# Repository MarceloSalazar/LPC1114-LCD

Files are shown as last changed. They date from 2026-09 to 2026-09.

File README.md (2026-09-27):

# LPC1114-LCD

Placa basada en el microcontrolador **NXP LPC1114FN28 (ARM Cortex-M0, DIP-28)** con pantalla **LCD 1602**, LEDs,
pulsadores y buzzer. Su uso principal es un **temporizador Pomodoro**, aunque también sirve como reloj con alarma.
Se programa en C.

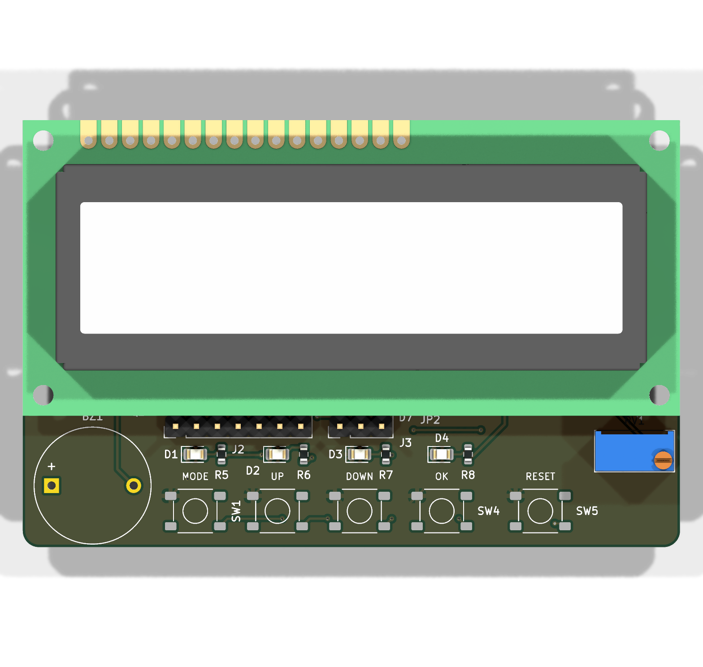
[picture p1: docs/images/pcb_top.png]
PCB, vista superior


**Esquemático:** [docs/hardware/LPC1114-LCD_schematic.pdf](docs/hardware/LPC1114-LCD_schematic.pdf)

| Fase | Contenido | Estado |
|---|---|---|
| 1 | Hardware v1.2: PCB de 2 capas montado por JLCPCB (PCBA) con componentes Basic | Listo para fabricar |
| 1b | Caja impresa en 3D de dos piezas (FreeCAD) | Lista: STEP + STL en [enclosure/](enclosure) |
| 2 | Firmware en C: temporizador Pomodoro / reloj (+ tests) | Pendiente |

## Características (v1.2)

- **MCU**: LPC1114FN28/102, 50 MHz, 32 kB flash, 4 kB RAM, en zócalo DIP-28. La base de tiempos es un cristal de 12 MHz de ±10 ppm.
- **Alimentación**: micro USB (5 V) con protección ESD USBLC6-2SC6 y regulador XC6206 de 3,3 V.
  Si no montas el USBLC6, puenteas con estaño **JP3** y **JP4**.
- **USB-serie**: CH340C en el mismo conector micro USB. Además, pads UART de 1 × 3 (GND, RX, TX) a 3,3 V.
  Con los puentes **JP5** y **JP6** eliges si la UART del MCU va al CH340 (de fábrica) o a J3.
- **Programación**: pads de 1 × 7 (3V3, SWDIO, SWCLK, RESET, GND, SCL, SDA) para un programador CMSIS-DAP.
  Los pines SCL y SDA quedan libres para módulos I2C. También se puede programar con el bootloader ISP por UART,
  de forma automática si se cierran los puentes JP1 y JP2.
- **LCD 1602** en modo 4 bits, montado encima del PCB. El footprint es de 18 pines: 16 estándar más 2 para módulos RGB.
  La retroiluminación se regula por PWM y el contraste con un trimmer multivuelta.
- **Interfaz de usuario**: 4 pulsadores (MODE/ISP, UP, DOWN, OK), RESET, 3 LEDs y LED de encendido,
  y buzzer piezoeléctrico TDK PS1420P02CT.
- **RTC opcional (DNP)**: la cara inferior tiene la huella de un DS3231MZ, su condensador y un portapilas CR2032 SMD, en el bus I2C de J2.
  No se montan; quedan para una ampliación futura.
- **PCB**: **80 × 52 mm**, 2 capas. JLCPCB monta todos los componentes SMD (una sola cara, casi todos Basic).
  Tú sueldas 7 componentes: el LPC1114, el LCD, el trimmer, el buzzer, el USBLC6 y las 2 tiras de pines.

## Estructura del repositorio

```
LPC1114-LCD/
├── hardware/                 Proyecto KiCad 10
│   ├── LPC1114-LCD.kicad_pro/.kicad_sch/.kicad_pcb
│   ├── lib/                  Símbolos y footprints propios
│   ├── fabrication/          Gerber (.zip), BOM + CPL de JLCPCB, soldadura manual, opciones DNP, STEP
│   └── scripts/              export_fab.ps1: ERC/DRC y generación de todos los ficheros
├── enclosure/                Caja 3D (FreeCAD): script paramétrico, STEP y STL
├── firmware/                 Fase 2 (en C)
│   ├── app/                  Aplicación; inc/board.h contiene el mapa de pines
│   ├── lib/                  CMSIS / drivers
│   └── tests/                Tests unitarios
└── docs/
    ├── datasheets/           Hojas de datos
    ├── hardware/             Notas de diseño, revisión para JLCPCB, esquemático en PDF
    └── images/               Renders del PCB y de la caja
```

## Mapa de pines (LPC1114FN28)

| Pin | Puerto | Función en la placa | Notas |
|----:|---|---|---|
| 1  | PIO0_8  | BTN_OK (SW4) | Activo en bajo, pull-up de 10k |
| 2  | PIO0_9  | BTN_UP (SW2) | Activo en bajo |
| 3  | SWCLK | SWD (J2-3) | |
| 4  | PIO0_11 | LCD_BL (PWM CT32B0_MAT3) | Retroiluminación, activo en alto. IOCON FUNC=1 |
| 5  | PIO0_5  | I2C SDA (J2-7) | Expansión y RTC opcional; pull-up de 4k7 |
| 6  | PIO0_6  | LCD D7 | |
| 9  | PIO1_0  | LCD D6 | IOCON FUNC=1 |
| 10 | PIO1_1  | LCD D5 | IOCON FUNC=1 |
| 11 | PIO1_2  | LCD D4 | IOCON FUNC=1 |
| 12 | SWDIO | SWD (J2-2) | |
| 13 | PIO1_4  | LCD E | |
| 14 | PIO1_5  | LCD RS | |
| 15 | PIO1_6  | UART RXD | Desde el CH340 (1k en serie) o J3-2, según JP5 |
| 16 | PIO1_7  | UART TXD | Hacia el CH340 o J3-3, según JP6 |
| 17 | PIO1_8  | BTN_DOWN (SW3) | Activo en bajo |
| 18 | PIO1_9  | BUZZER (PWM CT16B1_MAT0) | Activo en alto (NPN hacia el piezo a 5 V) |
| 19/20 | XTALOUT/XTALIN | Cristal de 12 MHz | |
| 23 | RESET | RESET (SW5, J2-4, CH340 DTR vía JP1) | |
| 24 | PIO0_1  | BTN_MODE (SW1) / ISP | Pulsado durante el reset: arranca el bootloader UART |
| 25 | PIO0_2  | LED1 (rojo) | Activo en alto |
| 26 | PIO0_3  | LED2 (amarillo) | Activo en alto |
| 27 | PIO0_4  | I2C SCL (J2-6) | Expansión y RTC opcional; pull-up de 4k7 |
| 28 | PIO0_7  | LED3 (verde) | Activo en alto |

El LCD tiene R/W a GND (solo escritura) y se controla con lógica de 3,3 V. Este mapa también está en
[firmware/app/inc/board.h](firmware/app/inc/board.h).

## Fabricación y montaje en JLCPCB

1. En <https://jlcpcb.com>, sube [hardware/fabrication/LPC1114-LCD_JLCPCB.zip](hardware/fabrication/LPC1114-LCD_JLCPCB.zip)
   y elige 2 capas, 1,6 mm, HASL y el color que quieras.
   En *Remove Order Number* selecciona **Specify a location**: JLCPCB pone el número en la cara inferior, donde está el texto `JLCJLCJLCJLC`.
2. Activa **PCB Assembly**, en cara superior (*Top side*), y sube:
   - BOM: [LPC1114-LCD_JLCPCB_BOM.csv](hardware/fabrication/LPC1114-LCD_JLCPCB_BOM.csv) (24 líneas, cada una con su código LCSC).
   - CPL: [LPC1114-LCD_JLCPCB_CPL.csv](hardware/fabrication/LPC1114-LCD_JLCPCB_CPL.csv).
3. Antes de confirmar, **revisa la orientación de cada pieza** en la vista previa de JLCPCB. Presta especial atención a los SOT-23, SOIC-16, cristal,
   micro USB y pulsadores; si alguno aparece girado, corrígelo ahí mismo.
4. La lista de componentes que sueldas tú está en [LPC1114-LCD_hand_solder.csv](hardware/fabrication/LPC1114-LCD_hand_solder.csv).
   Los componentes opcionales (DNP) del RTC están en [LPC1114-LCD_DNP_options.csv](hardware/fabrication/LPC1114-LCD_DNP_options.csv).

### Puentes de soldadura

| Puente | De fábrica | Qué hacer |
|---|---|---|
| JP1 / JP2 | Abiertos | Ciérralos para que el CH340 controle RESET e ISP (`lpc21isp -control`) |
| JP3 / JP4 | Abiertos | Ciérralos **solo si no montas el USBLC6 (U5)** |
| JP5 / JP6 | 1-2 puenteado (CH340) | Para usar una UART externa en J3: corta la pista 1-2 y puentea 2-3 en los dos |

Detalles, tipo de cada componente y decisiones:
[docs/hardware/design-notes.md](docs/hardware/design-notes.md) y
[docs/hardware/schematic-review-jlcpcb.md](docs/hardware/schematic-review-jlcpcb.md).

Para regenerar los ficheros después de modificar el diseño en KiCad:

```powershell
powershell -ExecutionPolicy Bypass -File hardware\scripts\export_fab.ps1
```

## Caja

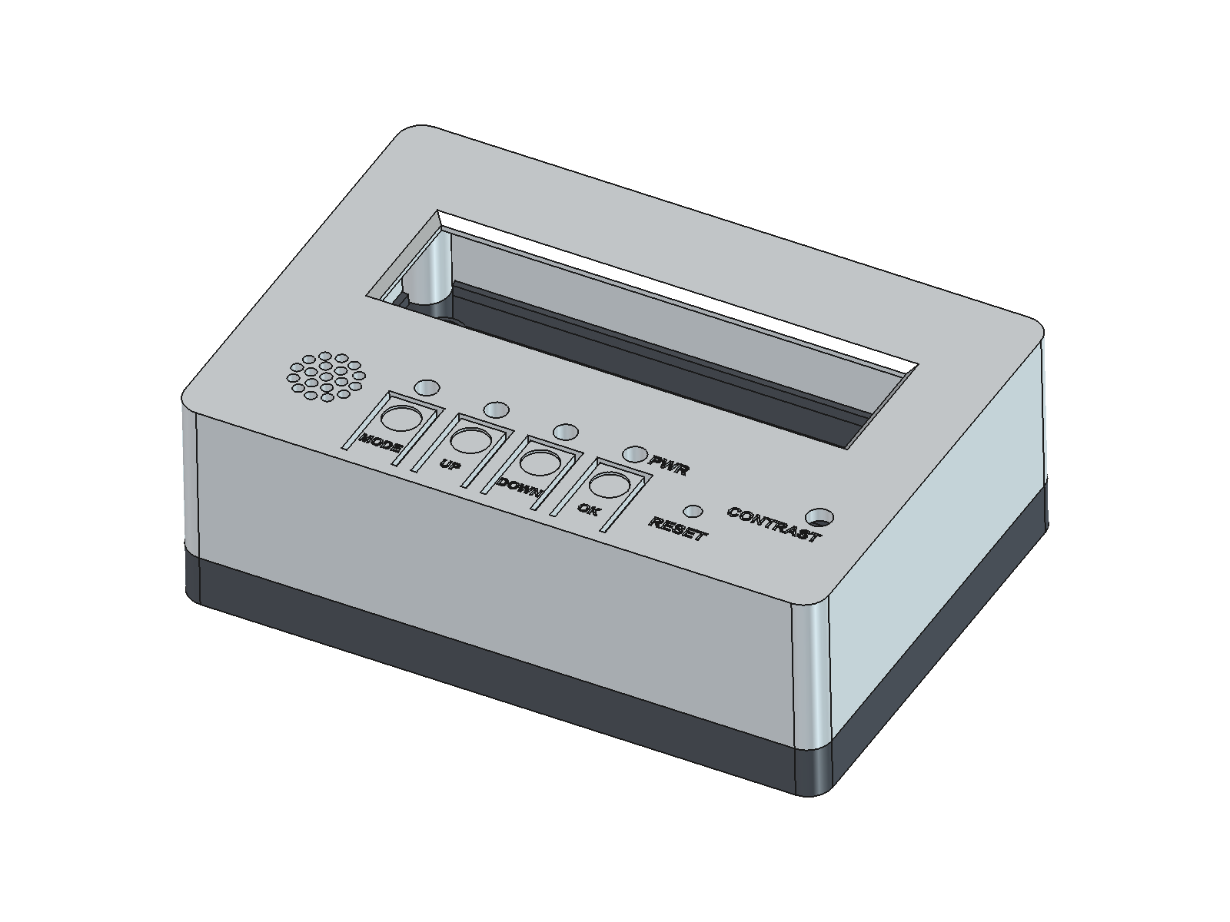
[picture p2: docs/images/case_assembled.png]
Caja montada


Dos piezas, la superior con el display y la inferior como base, de **92,8 × 64,8 × 31,4 mm**, unidas con 4 tornillos M3 × 16 desde abajo.
Los pulsadores van integrados en la tapa y los LEDs se ven a través de guías de luz de metacrilato de Ø3 mm.
Detalles, impresión y tornillería en [enclosure/README.md](enclosure/README.md).

## Programación (fase 2)

- **SWD**: conecta un programador CMSIS-DAP a J2 y usa [pyOCD](https://pyocd.io) (`pyocd flash -t lpc1114fn28 app.hex`) u OpenOCD.
- **UART ISP**: mantén MODE pulsado, pulsa RESET y usa `lpc21isp` o Flash Magic en el puerto COM del CH340.
  Con JP1 y JP2 cerrados con estaño, `lpc21isp -control` lo hace solo.

## Licencia

[MIT](LICENSE): hardware, firmware y documentación de este repositorio. Las hojas de datos de `docs/datasheets/` pertenecen a sus fabricantes.

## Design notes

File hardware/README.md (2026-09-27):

# Hardware: proyecto KiCad 10

| Fichero | Contenido |
|---|---|
| `LPC1114-LCD.kicad_pro` | Proyecto: clases de red (Default 0,25 mm; Power 0,3 mm para GND, +3V3, retroiluminación y buzzer) y reglas |
| `LPC1114-LCD.kicad_sch` | Esquemático (una hoja A3, organizada en bloques) |
| `LPC1114-LCD.kicad_pcb` | PCB de 2 capas, 80 × 52 mm (v1.2); RTC opcional y puentes en la cara inferior |
| `lib/LPC1114-LCD.kicad_sym` | Símbolos propios: `LPC1114FN28` (DIP-28), `LCD1602` (18 pines), `CH340C` (V3 como entrada de alimentación) |
| `lib/LPC1114-LCD.pretty/` | Footprints propios: `LCD1602_18pin` (fila de 1 × 18, taladros M2.5 de 75 × 31 mm), `SW_TS-1187A_5.1x5.1mm` (pulsador SMD) y `Buzzer_TDK_PS1420P02CT_D14mm_P10mm` |
| `fabrication/` | Gerber para JLCPCB (`.zip`), **BOM y CPL de PCBA** (`*_JLCPCB_BOM.csv`, `*_JLCPCB_CPL.csv`), lista de soldadura manual (`*_hand_solder.csv`), BOM completa y modelo 3D (`.step`) |
| `scripts/export_fab.ps1` | ERC y DRC, y exportación de todos los ficheros de fabricación y documentación |

Las librerías del proyecto se referencian con `${KIPRJMOD}` en `sym-lib-table` y `fp-lib-table`, así que el proyecto
se abre directamente sin configurar nada. El resto de símbolos, footprints y modelos 3D son los estándar de KiCad 10.

## Flujo de trabajo

1. Edita el esquemático y el PCB en KiCad.
2. En el PCB: *Herramientas → Actualizar PCB desde el esquemático* (F8) y vuelve a rellenar las zonas (B).
3. Ejecuta el script desde la raíz del repositorio:

   ```powershell
   powershell -ExecutionPolicy Bypass -File hardware\scripts\export_fab.ps1
   ```

   El script se detiene si el ERC o el DRC encuentran errores. Si todo es correcto, regenera
   `fabrication/LPC1114-LCD_JLCPCB.zip`, la BOM y la CPL de JLCPCB, la lista de soldadura manual, el STEP, el PDF del
   esquemático y los renders de `docs/images`.

## Campos de los símbolos

- `LCSC`: código de la pieza en JLCPCB/LCSC. Los símbolos que lo tienen los monta JLCPCB y entran en la BOM y la CPL de PCBA.
- `Assembly = USER`: componentes que se sueldan a mano (U1, DS1, RV1, BZ1, U5, J2, J3).
- **DNP** (atributo *Do Not Populate* y `Assembly = DNP ...`): RTC opcional U4, C9 y BT1 en la cara inferior.
  No entran en la BOM ni la CPL de JLCPCB; el script los lista en `fabrication/LPC1114-LCD_DNP_options.csv`.

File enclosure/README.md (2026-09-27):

# Caja impresa en 3D

Caja de dos piezas para la placa LPC1114-LCD v1.2: la **superior** (display) y la **inferior** (base).
Se cierra con **4 tornillos M3 × 16** que entran desde abajo.

| Montada | Despiece |
|---|---|
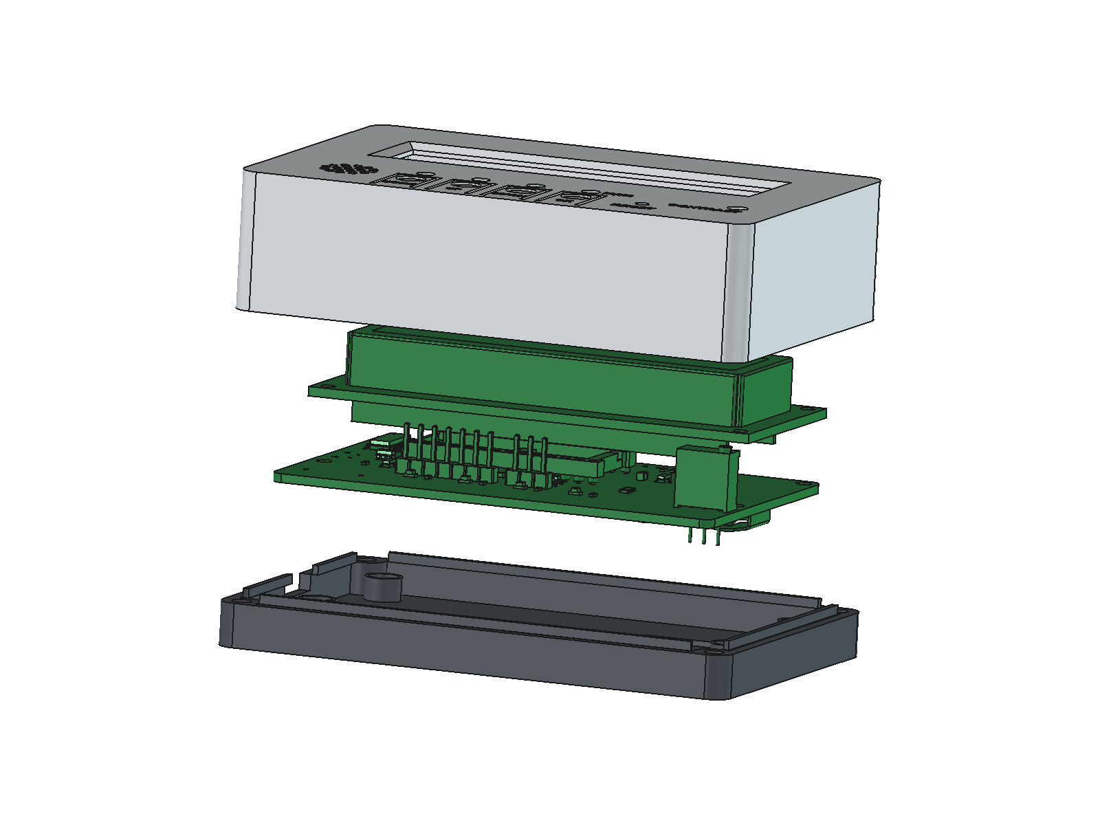
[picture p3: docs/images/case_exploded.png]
Despiece
| Caja montada |  |
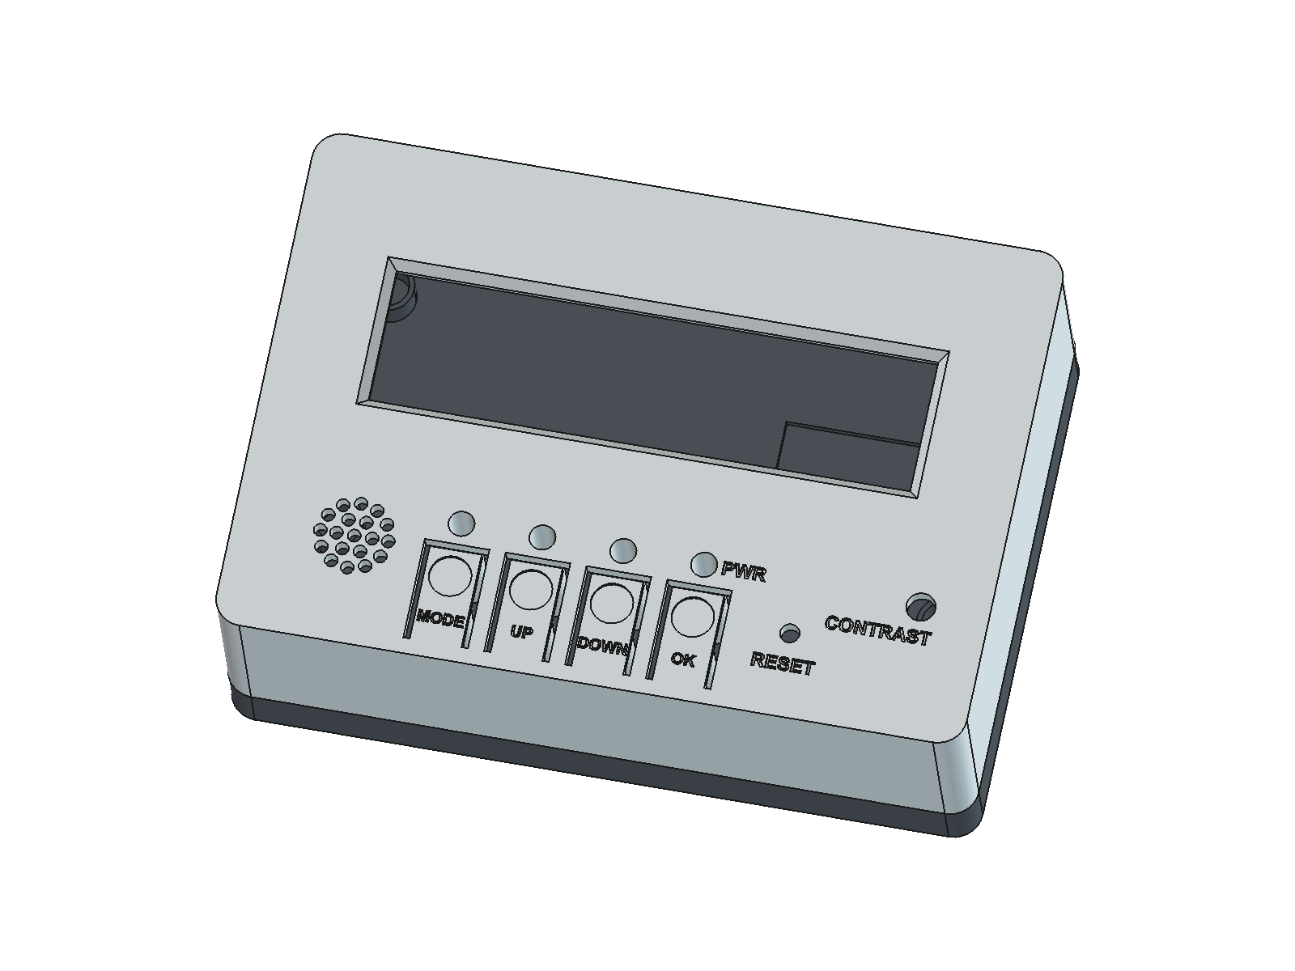
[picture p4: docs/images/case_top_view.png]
Vista superior
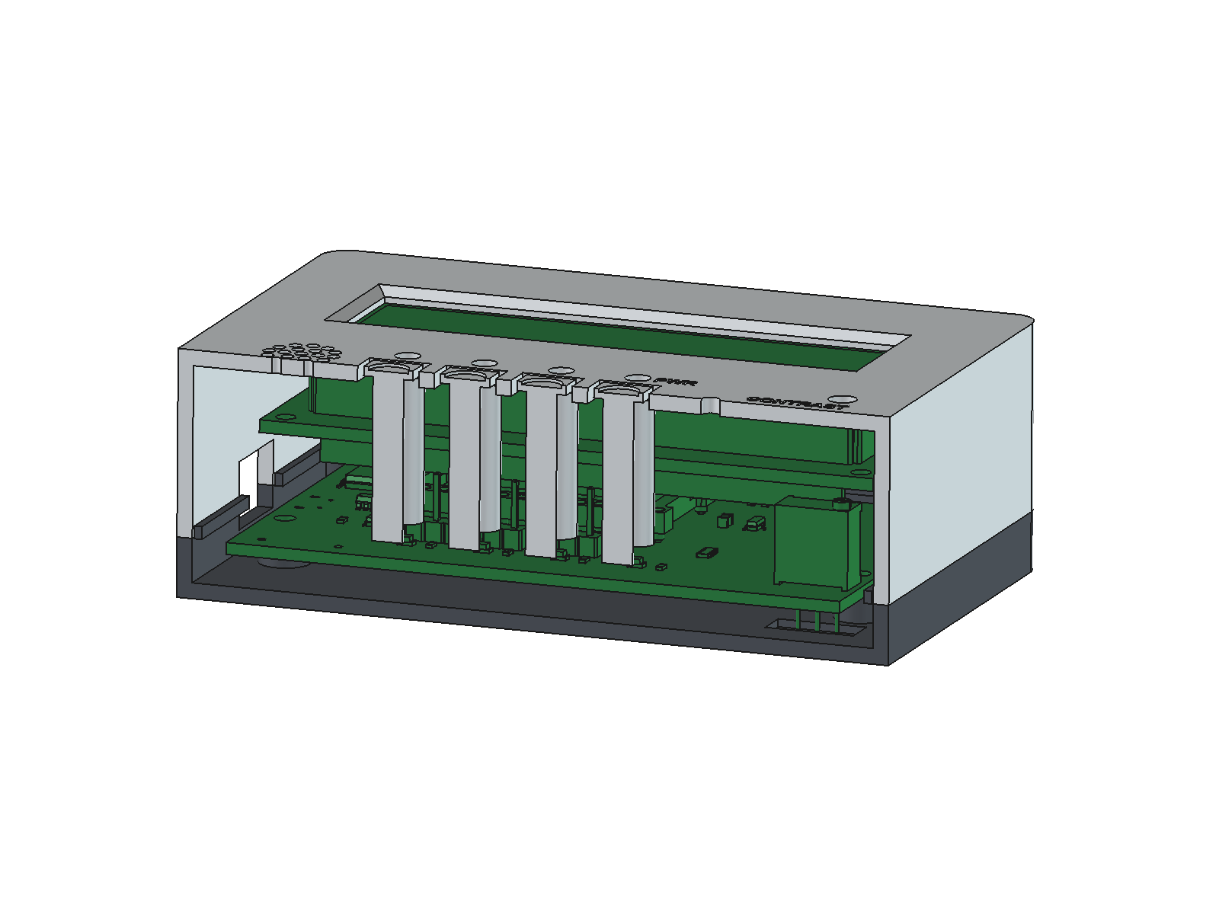
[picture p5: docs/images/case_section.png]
Corte por los pulsadores
|  |  |

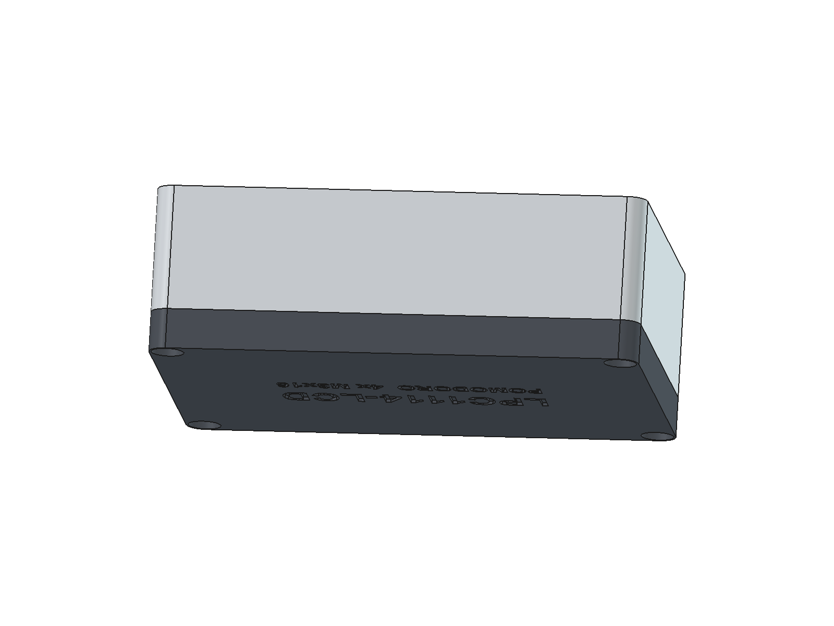
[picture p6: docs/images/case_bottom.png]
Vista inferior


## Ficheros

| Fichero | Uso |
|---|-----|
| `case_top.step`, `case_base.step` | Modelo CAD de cada pieza |
| `case_assembly.step` | Las dos piezas y el PCB con sus componentes (para comprobar ajustes) |
| `case_top.stl`, `case_base.stl` | Para el laminador, ya en la orientación de impresión |
| `LPC1114-LCD_case.FCStd` | Documento de FreeCAD |
| `case.py` | Script paramétrico que genera todo lo anterior |
| `render.py` | Genera las imágenes de `docs/images/case_*.png` |

## Características (v1.2)

- Medidas exteriores: **92,8 × 64,8 × 31,4 mm**. Paredes y fondo de 2 mm; la unión entre piezas está a la altura de la cara superior del PCB.
- **Ventana del LCD** de 67 × 17 mm con chaflán exterior. La tapa apoya sobre el marco del LCD (holgura de 0,2 mm).
- **Pulsadores integrados**: cada lengüeta flexible de la tapa (1,2 mm de grosor) tiene un vástago que baja hasta el
  pulsador SMD TS-1187A (1,5 mm de alto), con 0,4 mm de holgura.
- **Guías de luz** para los 4 LEDs SMD: agujeros de Ø3,2 mm con un tubo que baja hasta 2,2 mm por encima del LED.
  Van con varilla de metacrilato de Ø3 mm y unos 22 mm de largo (desde la superficie de la tapa hasta casi tocar el LED).
- Agujeros para el RESET (se pulsa con un clip) y el ajuste de **contraste** (tornillo del trimmer), rejilla para el buzzer y
  abertura para el **micro USB** en el lateral izquierdo.
- La base tiene 4 tubos bajo los taladros del LCD. En ellos se alojan las cabezas de los tornillos M2.5 que unen el PCB a los separadores del LCD.
  Al cerrar la caja, el PCB queda sujeto entre los tubos de la base y la tapa, que apoya sobre el LCD. Un labio perimetral centra la tapa.
- Comprobado en FreeCAD: **0 mm³ de interferencia** entre las dos piezas y el PCB (con el LCD a su altura real y las tiras J2/J3).
  Los pulsadores SMD, el buzzer y el micro USB no tienen modelo 3D en KiCad, así que los he comprobado con sus medidas.
- La base tiene un rebaje de 1 mm bajo el portapilas CR2032 del RTC opcional (cara inferior del PCB), así que se puede montar sin cambiar la caja.
- J2 (SWD) y J3 (UART) quedan dentro. Para programar por SWD hay que abrir la caja; con ella cerrada se puede programar por el USB (bootloader ISP).

## Impresión (PLA o PETG)

| Pieza | Orientación | Notas |
|---|---|---|
| Superior | Cara del display apoyada en la cama (el STL ya está girado) | Capa de 0,2 mm, 3 perímetros, relleno del 20 %. No necesita soportes. |
| Base | Fondo apoyado en la cama | Sin soportes. |

## Tornillería y piezas

| Cantidad | Pieza | Uso |
|---:|---|-----|
| 4 | Tornillo M3 × 16 (cabeza cilíndrica o alomada, Ø ≤ 6 mm) | Cierre de la caja desde abajo; rosca en el plástico (taladro guía de Ø2,5 mm) |
| 4 | Separador M2.5 de 11 mm hembra-hembra | LCD sobre el PCB |
| 8 | Tornillo M2.5 × 5 (cabeza de Ø ≤ 4,5 mm) | 4 arriba (LCD) y 4 abajo (PCB); las cabezas de abajo quedan dentro de los tubos de la base |
| 4 | Varilla de metacrilato de Ø3 mm y ~22 mm | Guías de luz de los LEDs |

Si prefieres insertos roscados de latón (M3, Ø4 × 5,7 mm), cambia `PILOT_D = 4.0` en `case.py` y regenera los ficheros.

## Montaje

1. Monta el LCD sobre el PCB con los separadores de 11 mm y corta las patillas de la cara inferior a menos de 2,5 mm.
2. Coloca el conjunto en la base: las cabezas de los tornillos M2.5 entran en los 4 tubos.
3. Mete las 4 varillas de luz en la tapa y ciérrala. El labio de la base la centra. Comprueba que los 4 pulsadores hacen clic.
4. Cierra con los 4 tornillos M3 × 16 desde abajo.

## Modificar la caja

Todas las medidas son parámetros al principio de `case.py`: holguras, grosores, altura del LCD (`LCD_STACK`), ventana, etc.
Para regenerar los ficheros STEP, STL y FCStd:

```powershell
& "C:\Program Files\FreeCAD 1.1\bin\freecadcmd.exe" enclosure\case.py
```

Las imágenes se regeneran con `render.py` desde la interfaz de FreeCAD (menú *Macro*) o lanzando `freecad.exe` con el script.

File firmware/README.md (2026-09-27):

# Firmware (fase 2): temporizador Pomodoro / reloj

> Pendiente. Esta carpeta contiene de momento la estructura y el mapa de pines de la placa.

## Estructura prevista

| Carpeta | Contenido |
|---|---|
| `app/inc/` | Cabeceras de la aplicación. [`board.h`](app/inc/board.h) define el mapa de pines de la v1.1 |
| `app/src/` | Código de la aplicación: arranque, drivers (GPIO, LCD, UART, PWM, I2C de expansión) y lógica del temporizador Pomodoro y del reloj |
| `lib/` | Dependencias externas (CMSIS-Core para Cortex-M0, cabeceras del LPC11xx) |
| `tests/` | Tests unitarios de la lógica independiente del hardware, ejecutados en el PC |

## Herramientas previstas

- Compilador: `arm-none-eabi-gcc` (Arm GNU Toolchain) con Make o CMake.
- Programación y depuración: CMSIS-DAP por SWD (J2) con pyOCD u OpenOCD, o UART ISP (lpc21isp / Flash Magic).
- Documentación de referencia: *UM10398 LPC111x User Manual* (ver [docs/datasheets](../docs/datasheets)).

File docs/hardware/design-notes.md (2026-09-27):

# Notas de diseño: LPC1114-LCD v1.2

Documento de referencia del hardware. El esquemático completo está en [LPC1114-LCD_schematic.pdf](LPC1114-LCD_schematic.pdf)
y el proyecto KiCad en [hardware/](../../hardware). Los motivos del paso a PCBA con componentes Basic están en
[schematic-review-jlcpcb.md](schematic-review-jlcpcb.md).

## 0. Cambios de la v1.2 respecto a la v1.1

| Cambio | Detalle |
|---|---|
| RTC opcional en la cara inferior (**DNP**) | U4 DS3231MZ+ (C107410) entre las filas del zócalo DIP, C9 de 100 nF y BT1: portapilas CR2032 SMD Keystone 3034 (C5213768). Van en el bus I2C de J2, con los pull-ups R3/R4 ya montados. No se montan y no entran en la BOM ni la CPL de JLCPCB; están en `LPC1114-LCD_DNP_options.csv`. |
| Puentes para omitir el USBLC6 | D+ y D- pasan en serie por U5 (conector → pines 1/3 → pines 6/4 → CH340). **JP3/JP4** (cara inferior, abiertos) lo puentean si no se monta. |
| Selección de UART | **JP5** (RX del MCU) y **JP6** (TX del MCU) son puentes de 3 pads en la cara inferior: 1-2 = CH340 (puenteado de fábrica con pista fina), 2-3 = J3. Así el CH340 y una UART externa nunca se conectan a la vez. |
| Caja | La base tiene un rebaje de 1 mm bajo el portapilas, que mide 4 mm de alto, por si se monta en el futuro. |

## 1. Cambios de la v1.1 respecto a la v1.0

| v1.0 (THT, montaje manual) | v1.1 (PCBA JLCPCB) |
|---|---|
| 80 × 76 mm | **80 × 52 mm**: casi toda la electrónica va debajo del LCD |
| RTC DS3231M + pila CR2032 | **Eliminados**. Como temporizador Pomodoro, la hora la lleva el propio LPC1114 con el cristal de 12 MHz de ±10 ppm |
| MCP1700 (TO-92) | **XC6206P332MR** (SOT-23, Basic C5446) |
| BC337 (TO-92) | **SS8050** (SOT-23, Basic C2150) |
| Fusible PTC 500 mA | Eliminado: el puerto USB del PC ya limita la corriente |
| Sin protección ESD en el USB | **USBLC6-2SC6** (lo sueldas tú) |
| Buzzer magnético de 12 mm con diodo | **Piezo TDK PS1420P02CT** (lo sueldas tú) con NPN y 1 kΩ en paralelo |
| Pull-ups de 5 V en el LCD (RN1) | Eliminados: lógica push-pull a 3,3 V (VIH del HD44780/ST7066 = 2,2 V) |
| Conector ARM de 10 pines + UART de 1 × 3 | **Pads de 1 × 7** (SWD + I2C) y **pads de 1 × 3** (UART) en el borde superior de la franja |
| Pulsadores de 6 × 6 mm THT | **TS-1187A** 5,1 × 5,1 × 1,5 mm SMD (Basic C318884) |
| LEDs de 3 mm, resistencias y condensadores THT | 0805 / 0603 Basic |
| 2 taladros M3 para fijar el PCB | Eliminados: el PCB queda sujeto entre base y tapa mediante los 4 separadores del LCD |

## 2. Decisiones principales

| Tema | Decisión | Motivo |
|---|---|---|
| Tensión del MCU | 3,3 V | El LPC111x funciona de 1,8 a 3,6 V, con 3,3 V nominal. |
| USB-serie | CH340C a 3,3 V (V3 unido a VCC), Extended C84681 | No hay USB-serie en Basic. El CP2102 (Preferred Extended) solo sale más barato a partir de unas 20 placas. |
| LCD | VDD a 5 V, R/W a GND, datos a 3,3 V | Solo se escribe, así que el LCD nunca envía 5 V al MCU. |
| ISP/RESET automáticos | Diodos B5819W desde DTR#/RTS#, con JP1/JP2 **abiertos** por defecto | Evita que abrir un terminal serie deje el MCU en reset. Se cierran con estaño para usar `lpc21isp -control`. |
| Buzzer | Piezo a 5 V con SS8050 en el lado bajo y 1 kΩ en paralelo | Con el piezo en carga capacitiva, la resistencia lo descarga en cada ciclo. Frecuencia de resonancia de unos 2 kHz. |
| Retroiluminación | R9 (pin 16), R10 y R11 (pines 17/18 RGB) de 100 Ω hacia el colector de Q1 | Si el módulo lleva resistencia propia y queda poco brillo, R9 puede bajarse. |
| Cabeceras | Solo pads; tú sueldas las tiras | JLCPCB no tiene que montar conectores THT, que serían Extended. |

## 3. Presupuesto de consumo

| Rail | Carga | Corriente aprox. |
|---|---|---|
| 3,3 V | LPC1114 a 48 MHz | ≤ 10 mA |
| 3,3 V | CH340C | ~12 mA |
| 3,3 V | LEDs (470 Ω y 1k) | ~10 mA |
| **3,3 V total** | | **~32 mA** (el XC6206 da 200 mA y disipa ~55 mW) |
| 5 V | LCD: lógica y retroiluminación | 15–50 mA |
| 5 V | Buzzer piezo | ~5 mA |
| **5 V total** | | **< 100 mA** |

## 4. Mecánica (para la caja)

- PCB de **80 × 52 mm**, 1,6 mm de grosor y esquinas con radio de 2 mm. Modelo 3D en [LPC1114-LCD.step](../../hardware/fabrication/LPC1114-LCD.step).
- Origen de las cotas: esquina superior izquierda del PCB, vista desde arriba (X hacia la derecha, Y hacia abajo).

| Elemento | X (mm) | Y (mm) | Notas |
|---|---:|---:|---|
| Taladros del LCD (M2.5, Ø2,7) | 2,5 / 77,5 | 2,5 / 33,5 | También sujetan el PCB dentro de la caja |
| Pin 1 del LCD | 8,0 | 2,5 | Fila de 18 pines a 2,54 mm |
| Micro USB (boca) | 0 | 25,0 | Borde izquierdo |
| Pulsadores MODE / UP / DOWN / OK / RESET | 21 / 31 / 41 / 51 / 63 | 47,6 | SMD de 5,1 × 5,1 mm y 1,5 mm de alto |
| LEDs D1 / D2 / D3 / D4 (PWR) | 21 / 31 / 41 / 51 | 40,7 | 0805 |
| Buzzer PS1420P02CT (centro) | 8,5 | 44,5 | Ø14 mm, patillas a 10 mm |
| Tornillo del trimmer RV1 | 77,96 | 41,44 | Multivuelta vertical, patillas a 2,54 mm |
| J2 (1 × 7), pin 1 → pin 7 | 18,6 → 33,84 | 37,3 | 3V3, SWDIO, SWCLK, RESET, GND, SCL, SDA |
| J3 (1 × 3), pin 1 → pin 3 | 38,6 → 43,68 | 37,3 | GND, RX (entrada), TX (salida) |

**Alturas bajo el LCD**: con la tira hembra de 8,5 mm, el LCD queda a unos 11 mm del PCB. Debajo solo hay SMD de menos
de 2 mm y el LPC1114 en su zócalo (~8 mm). J2 y J3 quedan fuera del LCD, así que admiten tiras rectas y cables dupont.

## 5. Montaje

1. JLCPCB monta los 43 componentes SMD de la [BOM](../../hardware/fabrication/LPC1114-LCD_JLCPCB_BOM.csv).
2. Tú sueldas los de la [lista de soldadura manual](../../hardware/fabrication/LPC1114-LCD_hand_solder.csv):
   - **U5, USBLC6-2SC6** (SOT-23-6, pads alargados): el primero, porque está al lado del USB.
   - **Zócalo DIP-28** (U1), **tira hembra del LCD**, **RV1** (trimmer 10k), **BZ1** (buzzer; el «+» va en el pad cuadrado).
   - **J2 y J3** si los necesitas.
3. **Prueba sin el MCU**: conecta el USB y comprueba +5 V y +3V3, y que el PC detecta el CH340.
4. Coloca el LPC1114 y el LCD, y ajusta RV1 hasta que se vean los caracteres.

## 6. Reglas de diseño y verificación

- Pista de 0,25 mm (0,3 mm en +3V3/GND/retroiluminación/buzzer), separación de 0,2 mm, vías de 0,6/0,3 mm y plano de GND en las dos caras.
- La separación entre agujero NPTH y cobre es de 0,15 mm. Solo afecta al micro USB, cuyo footprint oficial deja 0,18 mm entre sus pads y sus pivotes de fijación.
- Verificación v1.2: **ERC 0**, **DRC 0 errores y 0 avisos**, **paridad esquemático-PCB OK** y **0 conexiones sin rutar**.
  Para evitar una zona congestionada, la línea de +5V lleva un tramo pre-rutado sobre la tira del LCD y una vía de salida en el pin VBUS.

## 7. Configuración de los puentes de soldadura (cara inferior salvo JP1/JP2)

| Puente | De fábrica | Uso |
|---|---|-----|
| JP1 (DTR → RESET), JP2 (RTS → ISP) | Abiertos | Cerrar para programar automáticamente con `lpc21isp -control` |
| JP3 (D+), JP4 (D-) | Abiertos | Cerrar **solo** si no se monta el USBLC6 (U5) |
| JP5 (RX), JP6 (TX) | 1-2 (CH340) | UART externa en J3: cortar la pista 1-2 con un cúter y puentear 2-3 en los dos |

## 8. Puntos a verificar

1. **Orientación en JLCPCB**: revisa la vista previa de la CPL (SOT-23, SOIC-16, cristal de 4 pads, micro USB y pulsadores) antes de confirmar el pedido.
2. **Pulsador TS-1187A**: el footprint es propio. Solo se usan dos pads en diagonal, así que funciona sea cual sea la pareja de patillas unida por dentro.
3. **LCD RGB de 18 pines**: he supuesto que los pines 17 y 18 continúan la fila a 2,54 mm.
4. **Buzzer**: separación de patillas de 10 mm, según me indicaste.

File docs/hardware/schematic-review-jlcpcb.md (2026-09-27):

# Revisión del esquemático para montaje en JLCPCB (PCBA)

> **Estado: aplicada en la v1.1 (2026-09-27).** Decisiones finales:
> - Uso principal: temporizador Pomodoro. **RTC y pila eliminados**; la hora la lleva el LPC1114 con su cristal de 12 MHz.
> - **CH340C** mantenido. He comprobado CH340x, CH9102, CH343, CP210x, FT232/FT230X, PL2303 y XR21V: ninguno es Basic.
> - **Fusible PTC eliminado.**
> - **Trimmer** multivuelta vertical de 10k (THT, 3 patillas a 2,54 mm), **buzzer** TDK PS1420P02CT (Ø14, patillas a 10 mm) y
>   **USBLC6-2SC6**: los aportas y sueldas tú.
> - Conectores: **pads de 1 × 7** (SWD + I2C) y **pads de 1 × 3** (UART); los sueldas tú.
> - Resultado: PCB de **80 × 52 mm** (antes 80 × 76). JLCPCB monta 43 componentes SMD en 24 líneas de BOM,
>   de las que solo **2 son Extended**: CH340C y micro USB.

Fecha: 2026-09-27. Revisión de la **v1.0**, diseñada con componentes THT para soldar a mano.

**Nuevo requisito:** JLCPCB monta todos los componentes excepto el **LPC1114** y el **LCD**, y los componentes deben ser,
siempre que sea posible, de su librería **Basic** (<https://jlcpcb.com/parts/basic_parts>). Los Basic no tienen coste de
carga; los *Extended* suman una tarifa de carga por cada referencia distinta, unos 3 USD por pedido según las tarifas actuales.

He consultado la disponibilidad, el tipo de librería y el stock de cada componente con el buscador oficial de piezas de
JLCPCB, a fecha de esta revisión.

## 1. Resumen

- La v1.0 **no sirve para PCBA tal como está**: casi todo es THT y ninguno de sus componentes es Basic.
- Con SMD de tamaño 0603/0805 **se puede pasar a Basic** todo lo que sean resistencias, condensadores, LEDs, diodos,
  transistores, el regulador, el cristal y los pulsadores.
- **No existe equivalente Basic** para: el conversor USB-UART, el RTC, los conectores (USB, SWD, UART, portapilas), el
  buzzer, el trimmer y el fusible PTC. Son funciones que la placa necesita, así que esos componentes tendrán que ser Extended.
- JLCPCB **no tiene zócalo DIP-28 en stock**. El zócalo o el LPC1114 los montarías tú, igual que el LCD.

## 2. Tabla de componentes: v1.0 y propuesta v1.1

| Ref. | v1.0 (THT) | Propuesta v1.1 | LCSC | Librería | Notas |
|---|---|---|---|---|---|
| R (varias) | Axiales verticales | Resistencias 0603 ±1 % | C25804 (10k), C21190 (1k), C23162 (4k7), C23179 (470), C22775 (100), C22975 (2k) | **Basic** | |
| RN1, RN2 | SIP-7 / SIP-5 | Red 4 × 10k, 0603×4 | C29718 | **Basic** | RN1 necesita 6 resistencias: una red + 2 sueltas, o 2 redes |
| C 100 nF | Disco THT | 0603 X7R 50 V | C14663 | **Basic** | |
| C 10 µF | MLCC radial | 0805 X5R 25 V | C15850 | **Basic** | |
| C5, C6 | 18 pF THT | **33 pF** 0603 C0G | C1663 | **Basic** | El cristal nuevo tiene CL = 20 pF: C = 2 × (20 − ~4 pF parásitos) ≈ 33 pF |
| Y1 | 12 MHz HC-49 | 12 MHz 3225 (4 pads) | C9002 | **Basic** | ±10 ppm |
| U2 | MCP1700 TO-92 | **XC6206P332MR-G** SOT-23 | C5446 | **Basic** | 3,3 V, 200 mA, Vin máx. 6 V. El consumo total (~40 mA) cabe con margen |
| Q1, Q2 | BC337 TO-92 | **SS8050** SOT-23 | C2150 | **Basic** | Ic hasta 1,5 A |
| D5 | 1N4148 DO-35 | 1N4148W SOD-123 | C81598 | **Basic** | |
| D6, D7 | BAT43 DO-35 | **B5819W** SOD-123 | C8598 | **Basic** | Schottky del auto-ISP/RESET |
| D1–D4 | LEDs 3 mm | LEDs 0805: rojo, amarillo, verde | C84256, C2296, C2297 | **Basic** | La caja necesitará guías de luz (ver §4) |
| SW1–SW5 | 6 × 6 mm THT | **TS-1187A** 5,1 × 5,1 × 1,5 mm SMD | C318884 | **Basic** | Hay que alargar los vástagos de la caja |
| U3 | CH340C | CH340C (sin cambios) | C84681 | Extended | No hay USB-UART en Basic. Stock alto |
| U4 | DS3231MZ+ | DS3231MZ+TRL | C107410 | Extended | No hay RTC en Basic |
| J1 | Micro USB Würth | Micro USB XKB U254-051T-4BH83-F1S | C397452 | Extended | No hay conectores USB en Basic. KiCad trae su footprint |
| BT1 | CR2032 MYOUNG BS-07 (THT) | El mismo | C2979167 | Extended (THT) | JLCPCB lo suelda a mano |
| BZ1 | Buzzer 12 mm THT | **MLT-8530** SMD 8,5 × 8,5 mm, magnético pasivo | C94599 | Extended | Tensión nominal de 3,6 V: a 5 V necesita resistencia en serie (0603 Basic) |
| RV1 | Bourns 3296W | TC33X-2-103E SMD, o divisor fijo | C719176 | Extended / Basic | Ver decisión 2 |
| F1 | PTC 1206 | 1206L050YR, o eliminarlo | C163512 | Extended | Ver decisión 1 |
| J2 | Conector SWD 2 × 5 con carcasa | Tira de pines 2 × 5 a 2,54 mm (sin carcasa) | C492422 | Extended (THT) | La versión con carcasa no está en stock en JLCPCB |
| J3 | 1 × 3 | 1 × 3 a 2,54 mm | C2937625 | Extended (THT) | |
| JP1, JP2 | Puente de soldadura | Sin cambios | — | — | No son componentes |
| U1 | LPC1114 + zócalo DIP-28 | El mismo, **lo montas tú** | — | — | JLCPCB no tiene zócalo en stock |
| DS1 | LCD + tira hembra 1 × 16 | El mismo, **lo montas tú** (tira: C2894939) | — | — | |

**Resultado:** unas 20 líneas de la BOM (valores distintos) pasan a Basic. Quedan **8 Extended imprescindibles**:
CH340C, DS3231M, micro USB, portapilas, buzzer, J2, J3 y el trimmer. A ellos se suman el fusible y la protección ESD,
si decides incluirlos.

## 3. Otros hallazgos del esquemático

1. **Falta protección ESD en el USB.** Propongo añadir un USBLC6-2SC6 (C2687116, Extended, SOT-23-6) entre J1 y el CH340C.
2. **Condensadores del cristal**: con el cristal nuevo pasan de 18 pF a 33 pF, como se indica en la tabla.
3. **Buzzer SMD**: el MLT-8530 tiene una tensión nominal de 3,6 V. Propongo alimentarlo desde +5 V con una resistencia en serie
   de unos 22 Ω (Basic) y mantener el transistor, el diodo de protección y el pull-down de 10k.
4. **Pulsadores SMD de 1,5 mm de altura**: los vástagos de la tapa tienen que llegar hasta z ≈ 3,1 mm sobre el PCB (antes 6 mm).
5. **Tamaño del PCB**: con componentes SMD la franja inferior puede estrecharse. La placa podría quedar en unos 80 × 60 mm
   (ahora 80 × 76), con la caja proporcionalmente más pequeña.
6. **Ficheros para PCBA**: hacen falta la BOM en formato JLCPCB (Comment, Designator, Footprint, LCSC) y el fichero de posiciones (CPL).
   El campo `LCSC` se añadirá a cada símbolo.
7. **Montaje a una sola cara**: todos los componentes SMD irán en la cara superior, que es la opción más barata de JLCPCB.
8. Sin cambios: el conexionado del MCU, del LCD, de los pulsadores, de la UART y del SWD, y el mapa de pines de `board.h`.

## 4. Impacto en la caja

- **Vástagos de los pulsadores** unos 3 mm más largos.
- **LEDs 0805 a ras del PCB**, unos 20 mm por debajo de la tapa. Para que se vean hacen falta guías de luz: varilla acrílica de Ø3 mm
  o impresas en filamento transparente. La tapa puede llevar el alojamiento para ellas.
- Si el PCB se reduce, la caja se regenera con los mismos parámetros.

## 5. Decisiones pendientes

1. **Fusible PTC (F1)**: eliminarlo (el puerto USB del PC ya limita la corriente) o mantenerlo (Extended).
2. **Contraste (RV1)**: trimmer SMD (Extended, ajustable) o divisor fijo con resistencias Basic (sin ajuste).
3. **Protección ESD en el USB**: añadirla (Extended) o no.
4. **Tamaño**: reducir el PCB y la caja aprovechando el SMD.

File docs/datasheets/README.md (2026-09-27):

# Hojas de datos

## Incluidas en el repositorio

| Fichero | Componente |
|---|---|
| [LPC111X.pdf](LPC111X.pdf) | NXP LPC1110/11/12/13/14/15: datasheet (rev 9.2) |
| [LCD1602.pdf](LCD1602.pdf) | Vishay LCD-016N002B-CFH-ET: LCD de 16 × 2 caracteres (controlador ST7066) |

## Enlaces al resto de componentes

| Ref. | Componente | Enlace |
|---|---|---|
| U1 | LPC111x, **manual de usuario UM10398** (imprescindible para el firmware) | Página del LPC1114 en <https://www.nxp.com> → *Documentation* → *User Manual* (UM10398) |
| U2 | Torex XC6206P332MR (LDO de 3,3 V), LCSC C5446 | <https://www.lcsc.com/product-detail/C5446.html> |
| U3 | WCH CH340C (USB-UART), LCSC C84681 | <https://www.wch-ic.com/downloads/CH340DS1_PDF.html> |
| U5 | ST USBLC6-2SC6 (protección ESD USB) | <https://www.st.com/en/protections-and-emi-filters/usblc6-2.html> |
| DS1 | Sitronix ST7066U (controlador del LCD, compatible con HD44780) | <https://www.sparkfun.com/datasheets/LCD/st7066.pdf> |
| Q1, Q2 | SS8050 (NPN, SOT-23), LCSC C2150 | <https://www.lcsc.com/product-detail/C2150.html> |
| D6, D7 | B5819W (Schottky, SOD-123), LCSC C8598 | <https://www.lcsc.com/product-detail/C8598.html> |
| Y1 | YXC X322512MSB4SI, 12 MHz 3225 (CL = 20 pF), LCSC C9002 | <https://www.lcsc.com/product-detail/C9002.html> |
| SW1–SW5 | XKB TS-1187A-B-A-B, pulsador SMD de 5,1 × 5,1 mm, LCSC C318884 | <https://www.lcsc.com/product-detail/C318884.html> |
| J1 | XKB U254-051T-4BH83-F1S (micro USB B), LCSC C397452 | <https://www.lcsc.com/product-detail/C397452.html> |
| BZ1 | TDK PS1420P02CT (buzzer piezo de Ø14 mm) | <https://www.digikey.es/es/products/detail/tdk/PS1420P02CT/935925> |

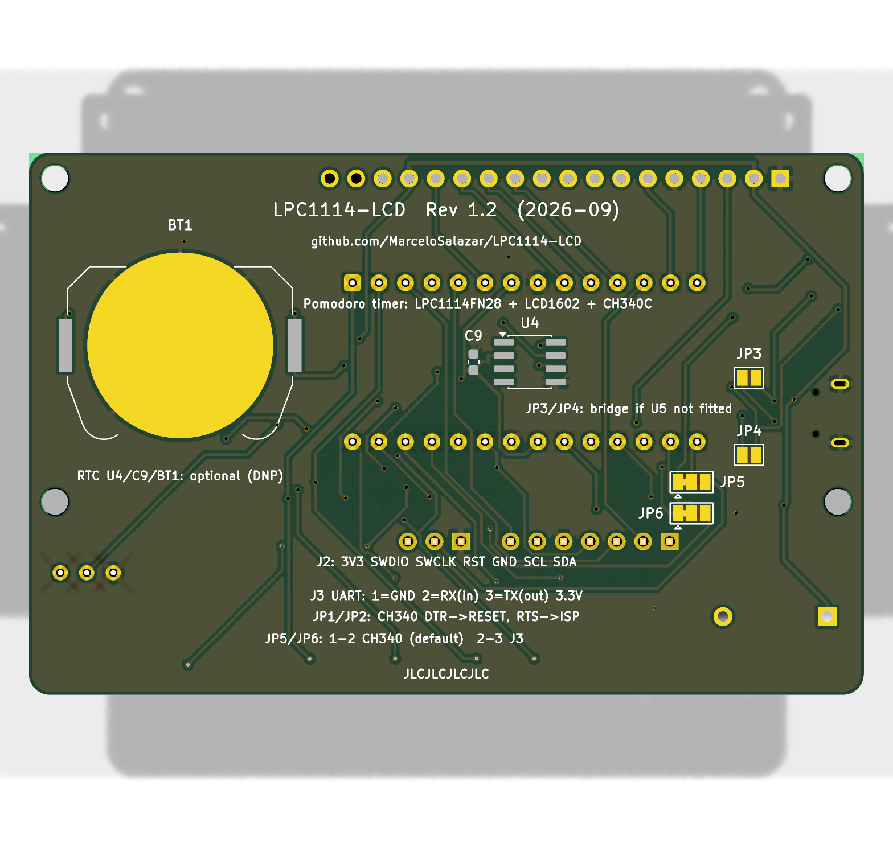
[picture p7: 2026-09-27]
docs/images/pcb_bottom.png

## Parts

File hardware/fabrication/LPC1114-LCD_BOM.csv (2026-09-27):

Reference | Value | Footprint | Qty | LCSC | Assembly | MPN | Description
BZ1 | PS1420P02CT | LPC1114-LCD:Buzzer_TDK_PS1420P02CT_D14mm_P10mm | 1 |  | USER | TDK PS1420P02CT (piezo, D14 mm, pitch 10 mm) | Buzzer, polarized
C1,C2 | 10uF | Capacitor_SMD:C_0805_2012Metric | 2 | C15850 |  |  | Unpolarized capacitor
C3,C4,C7,C8,C10 | 100nF | Capacitor_SMD:C_0603_1608Metric | 5 | C14663 |  |  | Unpolarized capacitor,VDD decoupling,VDDA decoupling
C5,C6 | 33pF | Capacitor_SMD:C_0603_1608Metric | 2 | C1663 |  |  | Unpolarized capacitor
D1 | Red | LED_SMD:LED_0805_2012Metric | 1 | C84256 |  |  | Light emitting diode
D2 | Yellow | LED_SMD:LED_0805_2012Metric | 1 | C2296 |  |  | Light emitting diode
D3 | Green | LED_SMD:LED_0805_2012Metric | 1 | C2297 |  |  | Light emitting diode
D4 | Green (PWR) | LED_SMD:LED_0805_2012Metric | 1 | C2297 |  |  | Light emitting diode
D6,D7 | B5819W | Diode_SMD:D_SOD-123 | 2 | C8598 |  |  | Schottky diode
DS1 | LCD1602 (HD44780/ST7066) | LPC1114-LCD:LCD1602_18pin | 1 |  | USER |  | Mounted on top with 1x16/1x18 female header (user)
J1 | USB_B_Micro | Connector_USB:USB_Micro-B_XKB_U254-051T-4BH83-F1S | 1 | C397452 |  | XKB U254-051T-4BH83-F1S | Micro USB B receptacle: power + USB-UART
J2 | SWD+I2C | Connector_PinHeader_2.54mm:PinHeader_1x07_P2.54mm_Vertical | 1 |  | USER |  | Debug/expansion: 1=3V3 2=SWDIO 3=SWCLK 4=RESET 5=GND 6=SCL 7=SDA
J3 | UART | Connector_PinHeader_2.54mm:PinHeader_1x03_P2.54mm_Vertical | 1 |  | USER |  | External 3.3V UART: GND / RX(in) / TX(out), select with JP5/JP6
Q1,Q2 | SS8050 | Package_TO_SOT_SMD:SOT-23 | 2 | C2150 |  |  | NPN transistor, base/emitter/collector
R1,R13,R15 | 10k | Resistor_SMD:R_0603_1608Metric | 3 | C25804 |  |  | Resistor
R2,R8,R12,R14,R16 | 1k | Resistor_SMD:R_0603_1608Metric | 5 | C21190 |  |  | Piezo discharge resistor,Resistor
R3,R4 | 4k7 | Resistor_SMD:R_0603_1608Metric | 2 | C23162 |  |  | Resistor
R5-R7 | 470 | Resistor_SMD:R_0603_1608Metric | 3 | C23179 |  |  | Resistor
R9-R11 | 100 | Resistor_SMD:R_0603_1608Metric | 3 | C22775 |  |  | Backlight Blue (18-pin only),Backlight Green (18-pin only),Backlight K (16-pin) / Red (18-pin)
RN2 | 10k | Resistor_SMD:R_Array_Convex_4x0603 | 1 | C29718 |  |  | 4 resistor network, parallel topology
RV1 | 10k | Potentiometer_THT:Potentiometer_Bourns_3296W_Vertical | 1 |  | USER |  | LCD contrast, multi-turn vertical trimmer 3 pins in line 2.54 mm (user)
SW1 | MODE/ISP | LPC1114-LCD:SW_TS-1187A_5.1x5.1mm | 1 | C318884 |  |  | Push button switch, generic, two pins
SW2 | UP | LPC1114-LCD:SW_TS-1187A_5.1x5.1mm | 1 | C318884 |  |  | Push button switch, generic, two pins
SW3 | DOWN | LPC1114-LCD:SW_TS-1187A_5.1x5.1mm | 1 | C318884 |  |  | Push button switch, generic, two pins
SW4 | OK | LPC1114-LCD:SW_TS-1187A_5.1x5.1mm | 1 | C318884 |  |  | Push button switch, generic, two pins
SW5 | RESET | LPC1114-LCD:SW_TS-1187A_5.1x5.1mm | 1 | C318884 |  |  | Push button switch, generic, two pins
U1 | LPC1114FN28/102 | Package_DIP:DIP-28_W15.24mm_Socket | 1 |  | USER | NXP LPC1114FN28/102 + DIP-28 600mil socket | NXP LPC1114 ARM Cortex-M0 MCU, 32kB flash, 4kB SRAM, DIP-28 (LPC1114FN28/102)
U2 | XC6206P332MR-G | Package_TO_SOT_SMD:SOT-23 | 1 | C5446 |  | Torex XC6206P332MR-G | Positive 60-250mA Low Dropout Regulator, Fixed Output, SOT-23
U3 | CH340C | Package_SO:SOIC-16_3.9x9.9mm_P1.27mm | 1 | C84681 |  | WCH CH340C (SOIC-16, no crystal) | USB serial converter, SOIC-16. Project copy: V3 pin typed power_in because V3 is tied to VCC for 3.3V operation
U5 | USBLC6-2SC6 | Package_TO_SOT_SMD:SOT-23-6_Handsoldering | 1 |  | USER | ST USBLC6-2SC6 | USB ESD protection (hand-soldered by the user)
Y1 | 12MHz | Crystal:Crystal_SMD_3225-4Pin_3.2x2.5mm | 1 | C9002 |  | YXC X322512MSB4SI 12MHz CL=20pF | Four pin crystal, GND on pins 2 and 4

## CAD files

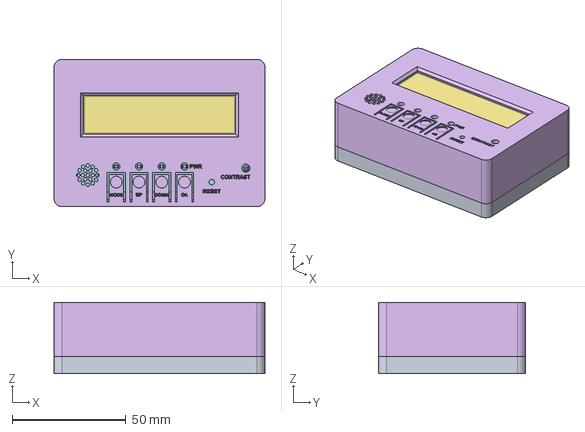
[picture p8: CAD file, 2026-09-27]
enclosure/case_assembly.step
92.8 x 64.8 x 31.4 mm

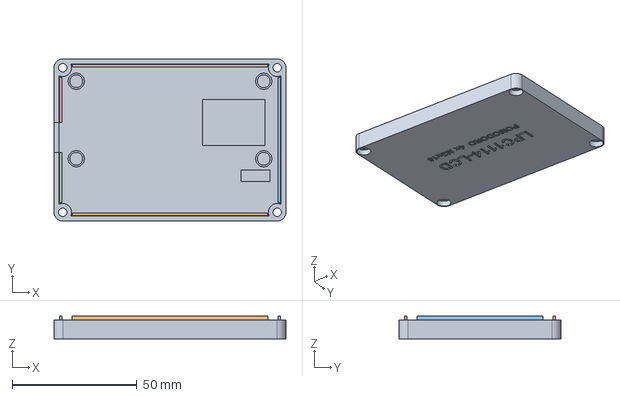
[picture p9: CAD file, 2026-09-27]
enclosure/case_base.step
92.8 x 64.8 x 9.20 mm

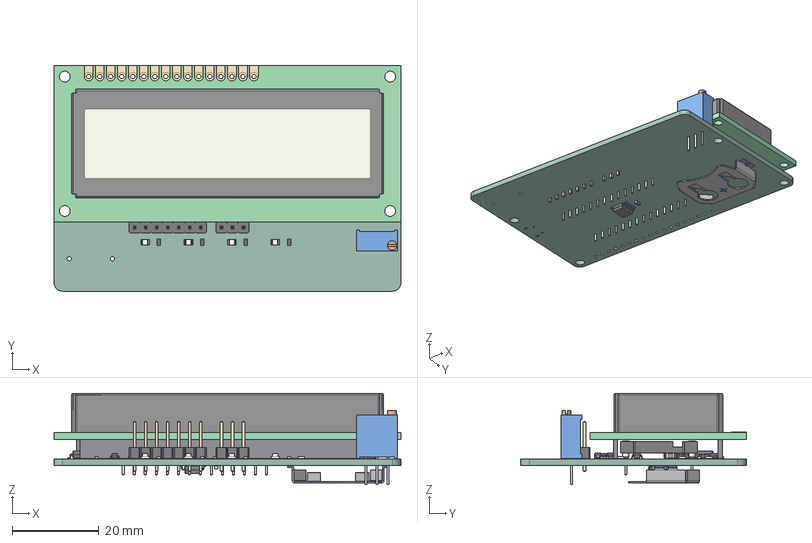
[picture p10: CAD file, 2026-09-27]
hardware/fabrication/LPC1114-LCD.step
80.0 x 52.0 x 21.0 mm
Pad_001_sp
R_0603_1608Metric x 16
LED_0805_2012Metric x 4
C_0805_2012Metric x 2
C_0603_1608Metric x 8
SOT-23-6
D_SOD-123 x 2
SOT-23 x 3
R_Array_Convex_4x0603
PinHeader_1x07_P254mm_Vertical
Potentiometer_Bourns_3296W_Vertical
PinHeader_1x03_P254mm_Vertical
Crystal_SMD_3225-4Pin_3.2x2.5mm
DIP_28_W1524mm_Socket
SOIC-16_3.9x9.9mm_P1.27mm
SOIC-8_3.9x4.9mm_P1.27mm
BatteryHolder_Keystone_3034_1x20mm
LPC1114-LCD_PCB

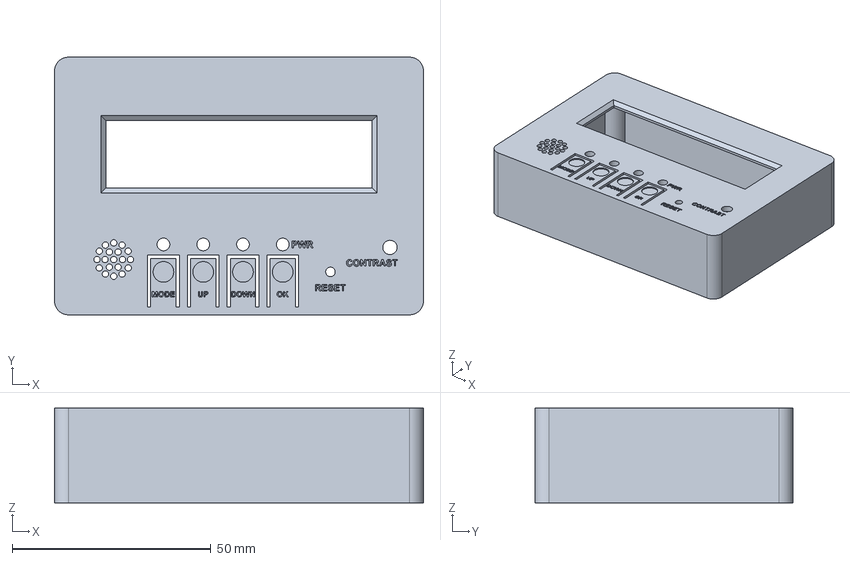
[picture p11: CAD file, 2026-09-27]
enclosure/case_top.step
92.8 x 64.8 x 23.8 mm

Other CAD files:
enclosure/LPC1114-LCD_case.FCStd
enclosure/case_base.stl
enclosure/case_top.stl

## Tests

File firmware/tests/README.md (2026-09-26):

# Tests

Tests unitarios de la fase 2, ejecutados en el PC (sin hardware), para la lógica que no depende de los periféricos:
cálculo de fecha y hora, conversión BCD del DS3231M, comparación de alarmas, máquina de estados de los menús y
antirrebote de los pulsadores.

Pendiente: elegir framework (p. ej. [Unity](https://github.com/ThrowTheSwitch/Unity)) y crear el Makefile de host.

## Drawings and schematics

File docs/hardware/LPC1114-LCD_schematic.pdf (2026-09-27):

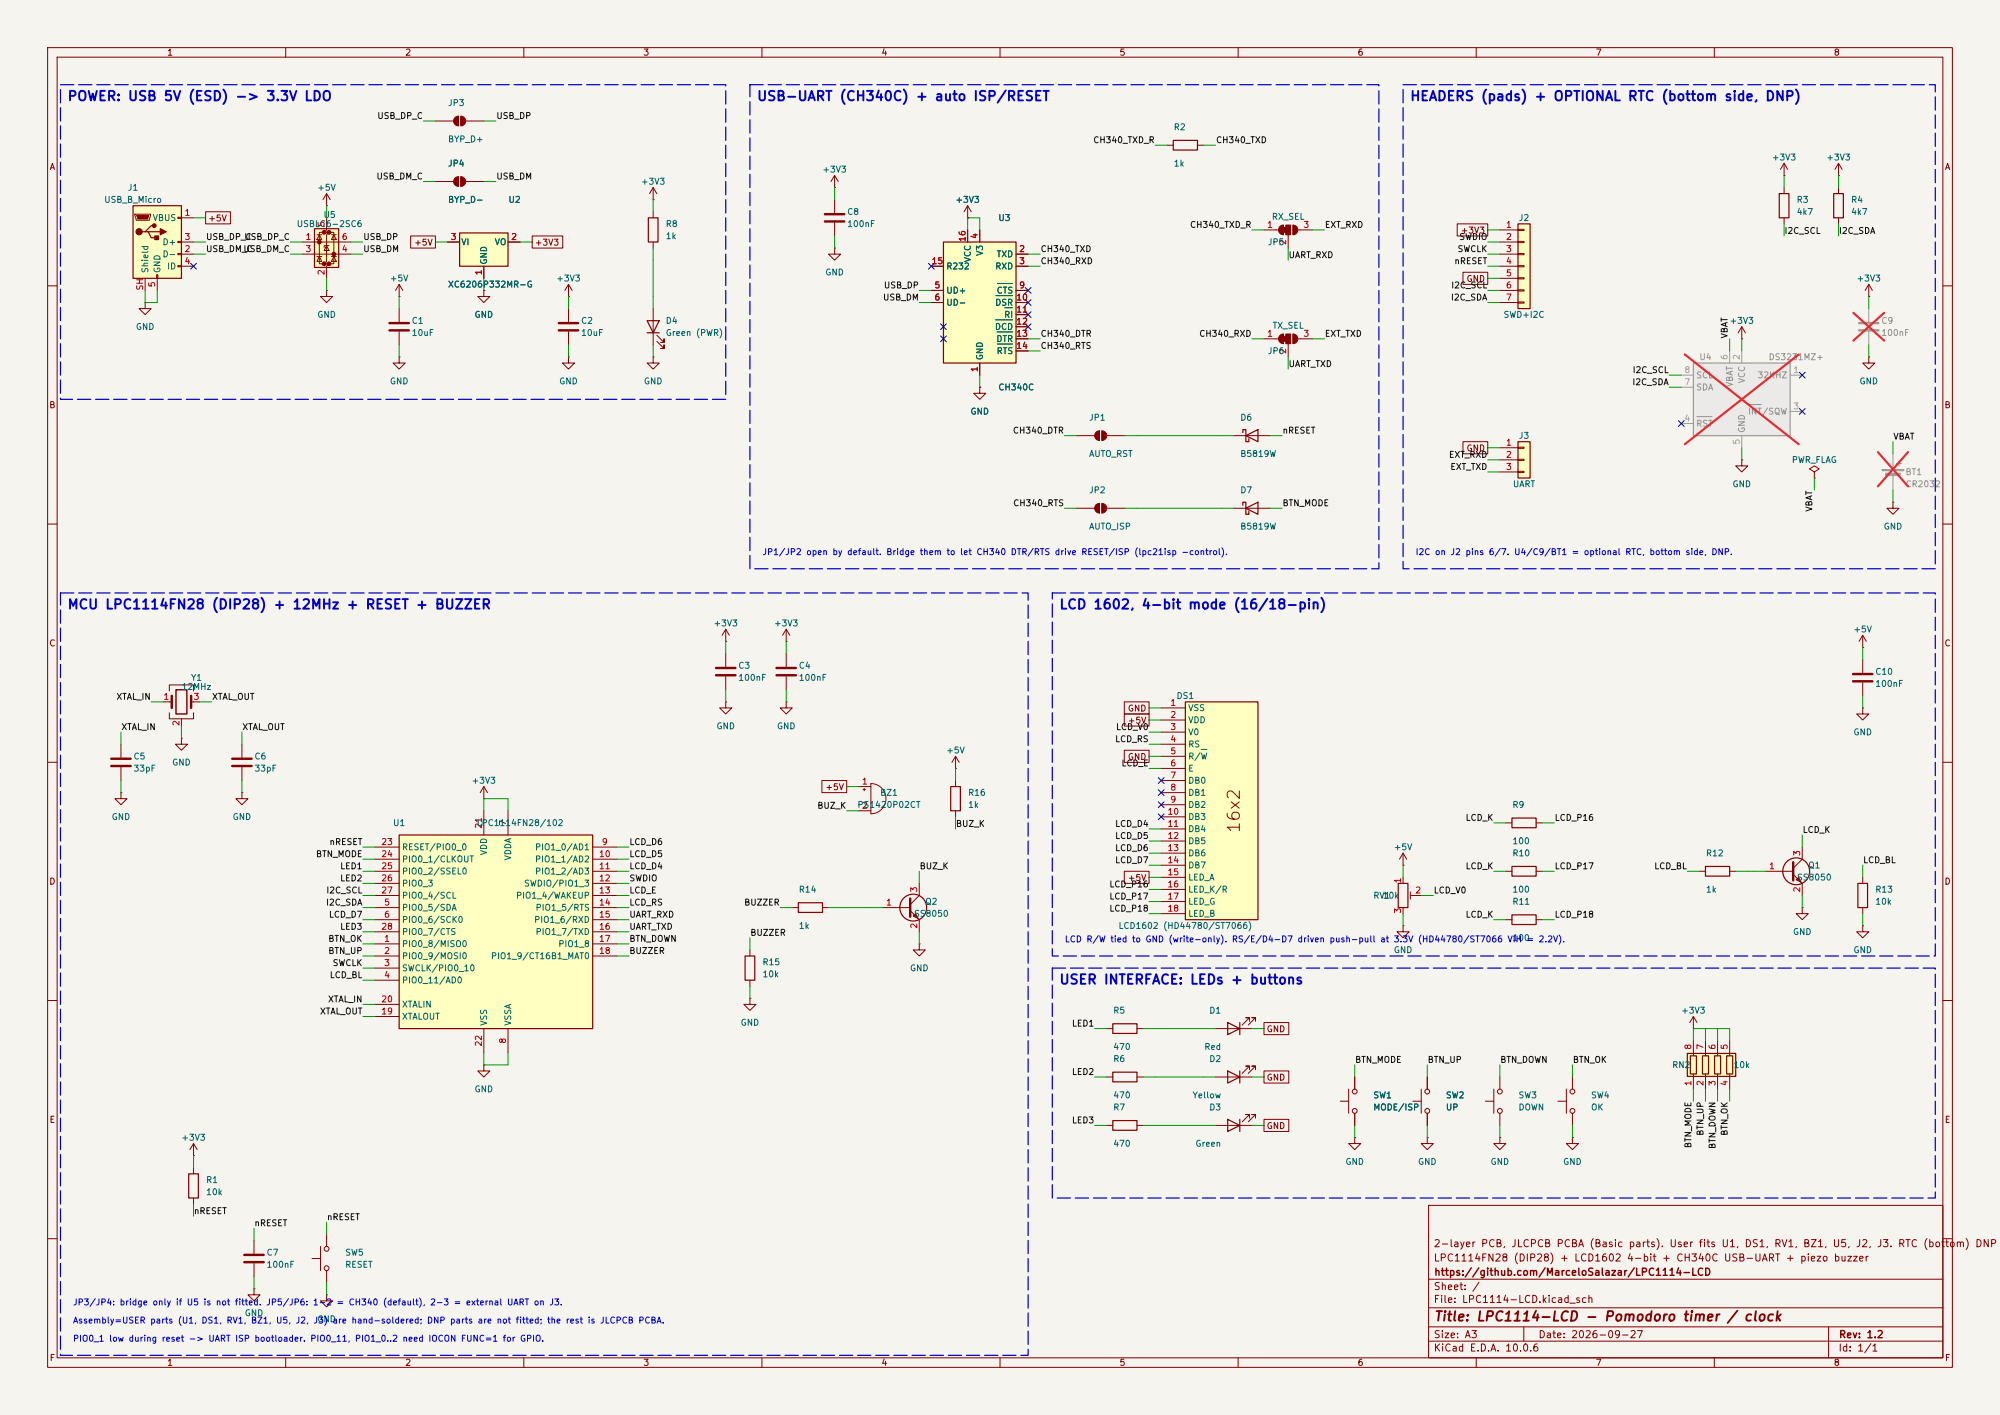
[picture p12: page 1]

I2C on J2 pins 6/7. U4/C9/BT1 = optional RTC, bottom side, DNP. POWER: USB 5V (ESD) -> 3.3V LDO

USB-UART (CH340C) + auto ISP/RESET

HEADERS (pads) + OPTIONAL RTC (bottom side, DNP)

4 UD+ 5 UD- 6 CTS 9 DSR 10 RI 11 DCD 12 DTR 13 RTS 14 R232 15 VCC 16 +3V3GND

4 UD+ 5 UD- 6 CTS 9 DSR 10 RI 11 DCD 12 DTR 13 RTS 14 R232 15 VCC 16 U3CH340C

JP1/JP2 open by default. Bridge them to let CH340 DTR/RTS drive RESET/ISP (lpc21isp -control).

LCD 1602, 4-bit mode (16/18-pin)
LED3 BUZ_K

LCD R/W tied to GND (write-only). RS/E/D4-D7 driven push-pull at 3.3V (HD44780/ST7066 VIH = 2.2V). PIO0_1 low during reset -> UART ISP bootloader. PIO0_11, PIO1_0..2 need IOCON FUNC=1 for GPIO. Assembly=USER parts (U1, DS1, RV1, BZ1, U5, J2, J3) are hand-soldered; DNP parts are not fitted; the rest is JLCPCB PCBA. JP3/JP4: bridge only if U5 is not fitted. JP5/JP6: 1-2 = CH340 (default), 2-3 = external UART on J3.

USER INTERFACE: LEDs + buttons

2-layer PCB, JLCPCB PCBA (Basic parts). User fits U1, DS1, RV1, BZ1, U5, J2, J3. RTC (bottom) DNP
LPC1114FN28 (DIP28) + LCD1602 4-bit + CH340C USB-UART + piezo buzzer
https://github.com/MarceloSalazar/LPC1114-LCD
Sheet: /
File: LPC1114-LCD.kicad_sch
Title: LPC1114-LCD - Pomodoro timer / clock

Size: A3 | Rev: 1.2 | F Date: 2026-09-27
KiCad E.D.A. 10.0.6 | Id: 1/1

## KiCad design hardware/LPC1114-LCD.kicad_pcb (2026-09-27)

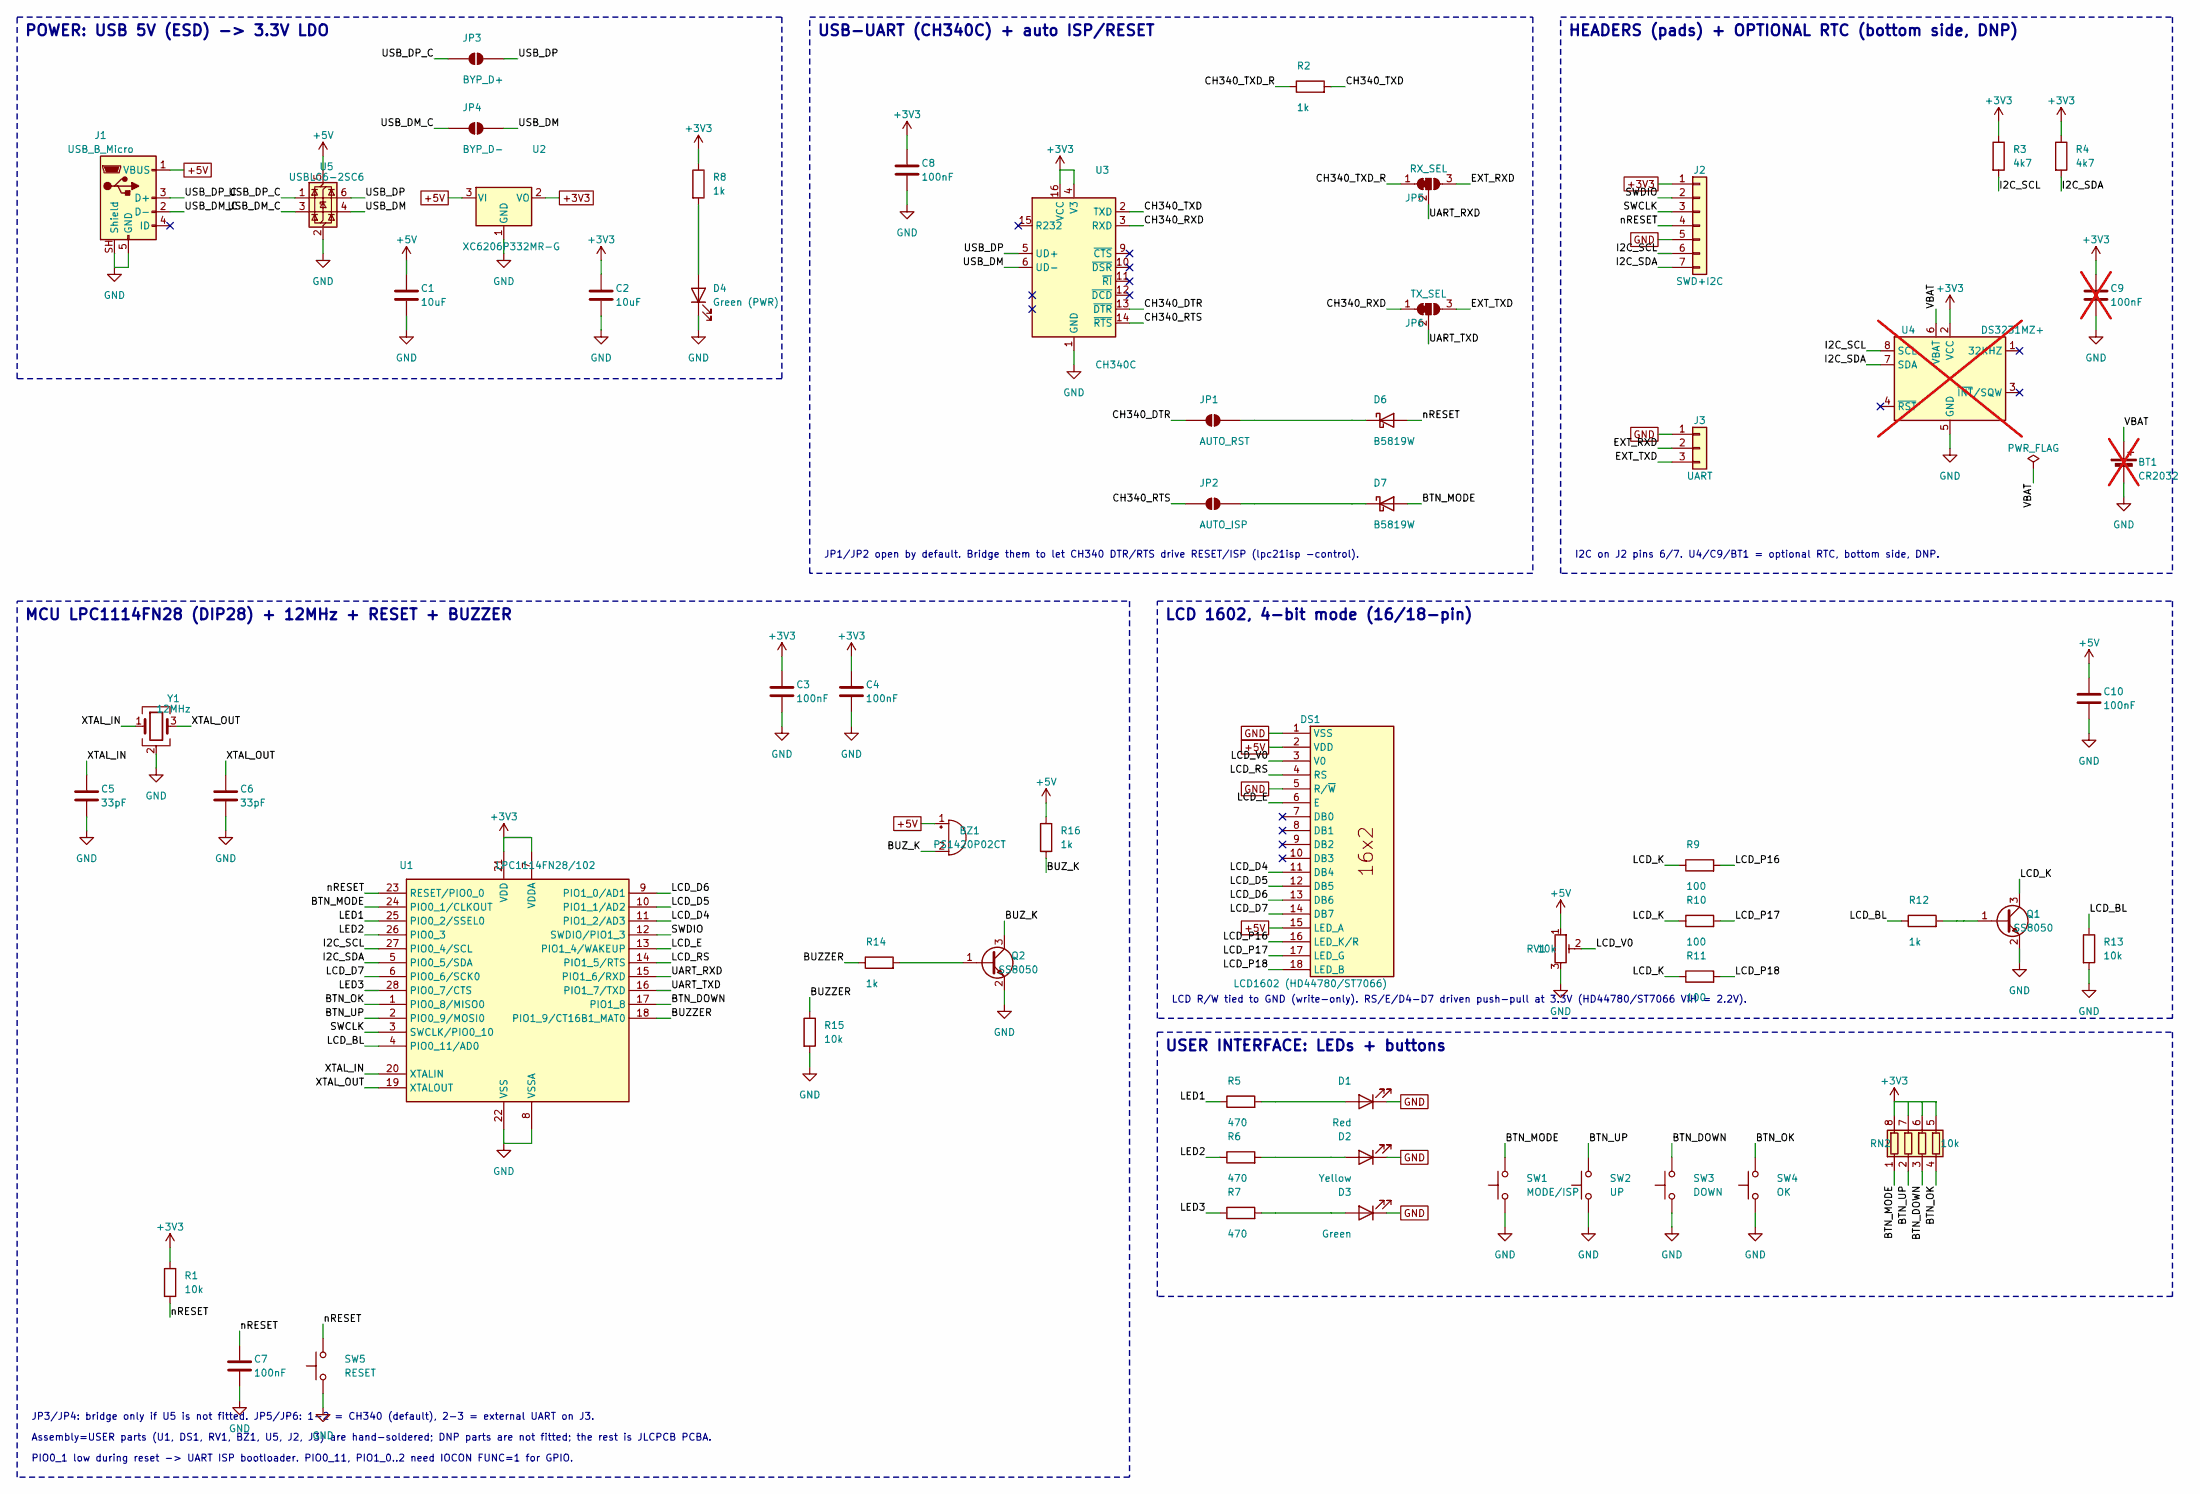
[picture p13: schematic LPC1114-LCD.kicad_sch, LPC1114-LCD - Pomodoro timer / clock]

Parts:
BT1: CR2032; BatteryHolder_Keystone_3034_1x20mm; MPN Keystone 3034 (SMD CR2032 holder); LCSC C5213768; not fitted
BZ1: PS1420P02CT; Buzzer_TDK_PS1420P02CT_D14mm_P10mm; MPN TDK PS1420P02CT (piezo, D14 mm, pitch 1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
C1, C2: 10uF; C_0805_2012Metric; LCSC C15850
C3, C4, C7, C8, C10: 100nF; C_0603_1608Metric; LCSC C14663
C5, C6: 33pF; C_0603_1608Metric; LCSC C1663
C9: 100nF; C_0603_1608Metric; LCSC C14663; not fitted
D1: Red; LED_0805_2012Metric; LCSC C84256
D2: Yellow; LED_0805_2012Metric; LCSC C2296
D3: Green; LED_0805_2012Metric; LCSC C2297
D4: Green (PWR); LED_0805_2012Metric; LCSC C2297
D6, D7: B5819W; D_SOD-123; LCSC C8598
DS1: LCD1602 (HD44780/ST7066); LCD1602_18pin
J1: USB_B_Micro; USB_Micro-B_XKB_U254-051T-4BH83-F1S; MPN XKB U254-051T-4BH83-F1S; LCSC C397452
J2: SWD+I2C; PinHeader_1x07_P2.54mm_Vertical
J3: UART; PinHeader_1x03_P2.54mm_Vertical
JP1: AUTO_RST; SolderJumper-2_P1.3mm_Open_Pad1.0x1.5mm
JP2: AUTO_ISP; SolderJumper-2_P1.3mm_Open_Pad1.0x1.5mm
JP3: BYP_D+; SolderJumper-2_P1.3mm_Open_Pad1.0x1.5mm
JP4: BYP_D-; SolderJumper-2_P1.3mm_Open_Pad1.0x1.5mm
JP5: RX_SEL; SolderJumper-3_P1.3mm_Bridged12_Pad1.0x1.5mm
JP6: TX_SEL; SolderJumper-3_P1.3mm_Bridged12_Pad1.0x1.5mm
Q1, Q2: SS8050; SOT-23; LCSC C2150
R1, R13, R15: 10k; R_0603_1608Metric; LCSC C25804
R2, R8, R12, R14, R16: 1k; R_0603_1608Metric; LCSC C21190
R3, R4: 4k7; R_0603_1608Metric; LCSC C23162
R5, R6, R7: 470; R_0603_1608Metric; LCSC C23179
R9, R10, R11: 100; R_0603_1608Metric; LCSC C22775
RN2: 10k; R_Array_Convex_4x0603; LCSC C29718
RV1: 10k; Potentiometer_Bourns_3296W_Vertical
SW1: MODE/ISP; SW_TS-1187A_5.1x5.1mm; LCSC C318884
SW2: UP; SW_TS-1187A_5.1x5.1mm; LCSC C318884
SW3: DOWN; SW_TS-1187A_5.1x5.1mm; LCSC C318884
SW4: OK; SW_TS-1187A_5.1x5.1mm; LCSC C318884
SW5: RESET; SW_TS-1187A_5.1x5.1mm; LCSC C318884
U1: LPC1114FN28/102; DIP-28_W15.24mm_Socket; MPN NXP LPC1114FN28/102 + DIP-28 600mil soc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
U2: XC6206P332MR-G; SOT-23; MPN Torex XC6206P332MR-G; LCSC C5446
U3: CH340C; SOIC-16_3.9x9.9mm_P1.27mm; MPN WCH CH340C (SOIC-16, no crystal); LCSC C84681
U4: DS3231MZ+; SOIC-8_3.9x4.9mm_P1.27mm; MPN Analog Devices DS3231MZ+ (+-5ppm MEMS R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; LCSC C107410; not fitted
U5: USBLC6-2SC6; SOT-23-6_Handsoldering; MPN ST USBLC6-2SC6
Y1: 12MHz; Crystal_SMD_3225-4Pin_3.2x2.5mm; MPN YXC X322512MSB4SI 12MHz CL=20pF; LCSC C9002

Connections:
+3V3: C2.1, C3.1, C4.1, C8.1, C9.1, J2.1, R1.1, R3.1, R4.1, R8.1, RN2.5 (R4.2), RN2.6 (R3.2), RN2.7 (R2.2), RN2.8 (R1.2), U1.7 (VDDA), U1.21 (VDD), U2.2 (VO), U3.4 (V3), U3.16 (VCC), U4.2 (VCC)
+5V: BZ1.1 (+), C1.1, C10.1, DS1.2 (VDD), DS1.15 (LED_A), J1.1 (VBUS), R16.1, RV1.1, U2.3 (VI), U5.5 (VBUS)
/BTN_DOWN: RN2.3 (R3.1), SW3.2, U1.17 (PIO1_8)
/BTN_MODE: D7.2 (A), RN2.1 (R1.1), SW1.2, U1.24 (PIO0_1/CLKOUT)
/BTN_OK: RN2.4 (R4.1), SW4.2, U1.1 (PIO0_8/MISO0)
/BTN_UP: RN2.2 (R2.1), SW2.2, U1.2 (PIO0_9/MOSI0)
/BUZZER: R14.1, R15.1, U1.18 (PIO1_9/CT16B1_MAT0)
/BUZ_K: BZ1.2 (-), Q2.3 (C), R16.2
/CH340_DTR: JP1.1 (A), U3.13 (~DTR)
/CH340_RTS: JP2.1 (A), U3.14 (~RTS)
/CH340_RXD: JP6.1 (A), U3.3 (RXD)
/CH340_TXD: R2.2, U3.2 (TXD)
/CH340_TXD_R: JP5.1 (A), R2.1
/EXT_RXD: J3.2, JP5.3 (B)
/EXT_TXD: J3.3, JP6.3 (B)
/I2C_SCL: J2.6, R3.2, U1.27 (PIO0_4/SCL), U4.8 (SCL)
/I2C_SDA: J2.7, R4.2, U1.5 (PIO0_5/SDA), U4.7 (SDA)
/LCD_BL: R12.1, R13.1, U1.4 (PIO0_11/AD0)
/LCD_D4: DS1.11 (DB4), U1.11 (PIO1_2/AD3)
/LCD_D5: DS1.12 (DB5), U1.10 (PIO1_1/AD2)
/LCD_D6: DS1.13 (DB6), U1.9 (PIO1_0/AD1)
/LCD_D7: DS1.14 (DB7), U1.6 (PIO0_6/SCK0)
/LCD_E: DS1.6 (E), U1.13 (PIO1_4/WAKEUP)
/LCD_K: Q1.3 (C), R9.1, R10.1, R11.1
/LCD_P16: DS1.16 (LED_K/R), R9.2
/LCD_P17: DS1.17 (LED_G), R10.2
/LCD_P18: DS1.18 (LED_B), R11.2
/LCD_RS: DS1.4 (RS), U1.14 (PIO1_5/RTS)
/LCD_V0: DS1.3 (V0), RV1.2
/LED1: R5.1, U1.25 (PIO0_2/SSEL0)
/LED2: R6.1, U1.26 (PIO0_3)
/LED3: R7.1, U1.28 (PIO0_7/CTS)
/SWCLK: J2.3, U1.3 (SWCLK/PIO0_10)
/SWDIO: J2.2, U1.12 (SWDIO/PIO1_3)
/UART_RXD: JP5.2 (C), U1.15 (PIO1_6/RXD)
/UART_TXD: JP6.2 (C), U1.16 (PIO1_7/TXD)
/USB_DM: JP4.2 (B), U3.6 (UD-), U5.4 (I/O2)
/USB_DM_C: J1.2 (D-), JP4.1 (A), U5.3 (I/O2)
/USB_DP: JP3.2 (B), U3.5 (UD+), U5.6 (I/O1)
/USB_DP_C: J1.3 (D+), JP3.1 (A), U5.1 (I/O1)
/VBAT: BT1.1 (+), U4.6 (VBAT)
/XTAL_IN: C5.1, U1.20 (XTALIN), Y1.1
/XTAL_OUT: C6.1, U1.19 (XTALOUT), Y1.3
/nRESET: C7.1, D6.2 (A), J2.4, R1.2, SW5.2, U1.23 (RESET/PIO0_0)
GND: BT1.2 (-), C1.2, C2.2, C3.2, C4.2, C5.2, C6.2, C7.2, C8.2, C9.2, C10.2, D1.1 (K), D2.1 (K), D3.1 (K), D4.1 (K), DS1.1 (VSS), DS1.5 (R/~W), J1.5 (GND), J1.SH (Shield), J2.5, J3.1, Q1.2 (E), Q2.2 (E), R13.2, R15.2, RV1.3, SW1.1, SW2.1, SW3.1, SW4.1, SW5.1, U1.8 (VSSA), U1.22 (VSS), U2.1 (GND), U3.1 (GND), U4.5 (GND), U5.2 (GND), Y1.2 (G), Y1.4 (G)
unnamed: D1.2 (A), R5.2
unnamed: D2.2 (A), R6.2
unnamed: D3.2 (A), R7.2
unnamed: D4.2 (A), R8.2
unnamed: D6.1 (K), JP1.2 (B)
unnamed: D7.1 (K), JP2.2 (B)
unnamed: Q1.1 (B), R12.2
unnamed: Q2.1 (B), R14.2

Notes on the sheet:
POWER: USB 5V (ESD) -> 3.3V LDO
USB-UART (CH340C) + auto ISP/RESET
HEADERS (pads) + OPTIONAL RTC (bottom side, DNP)
MCU LPC1114FN28 (DIP28) + 12MHz + RESET + BUZZER
LCD 1602, 4-bit mode (16/18-pin)
USER INTERFACE: LEDs + buttons
JP1/JP2 open by default. Bridge them to let CH340 DTR/RTS drive RESET/ISP (lpc21isp -control).
LCD R/W tied to GND (write-only). RS/E/D4-D7 driven push-pull at 3.3V (HD44780/ST7066 VIH = 2.2V).
PIO0_1 low during reset -> UART ISP bootloader. PIO0_11, PIO1_0..2 need IOCON FUNC=1 for GPIO.
Assembly=USER parts (U1, DS1, RV1, BZ1, U5, J2, J3) are hand-soldered; DNP parts are not fitted; the rest is JLCPCB PCBA.
I2C on J2 pins 6/7. U4/C9/BT1 = optional RTC, bottom side, DNP.
JP3/JP4: bridge only if U5 is not fitted. JP5/JP6: 1-2 = CH340 (default), 2-3 = external UART on J3.

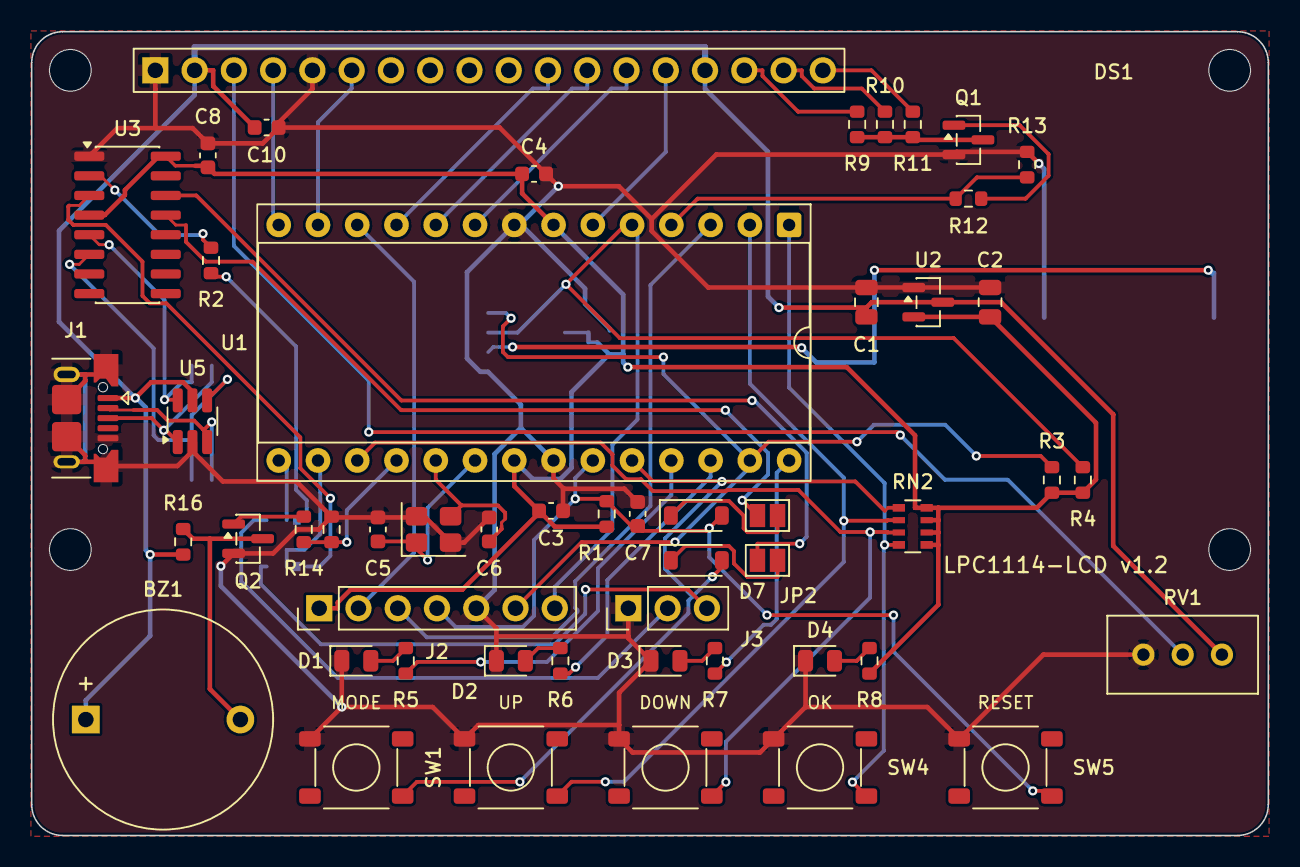
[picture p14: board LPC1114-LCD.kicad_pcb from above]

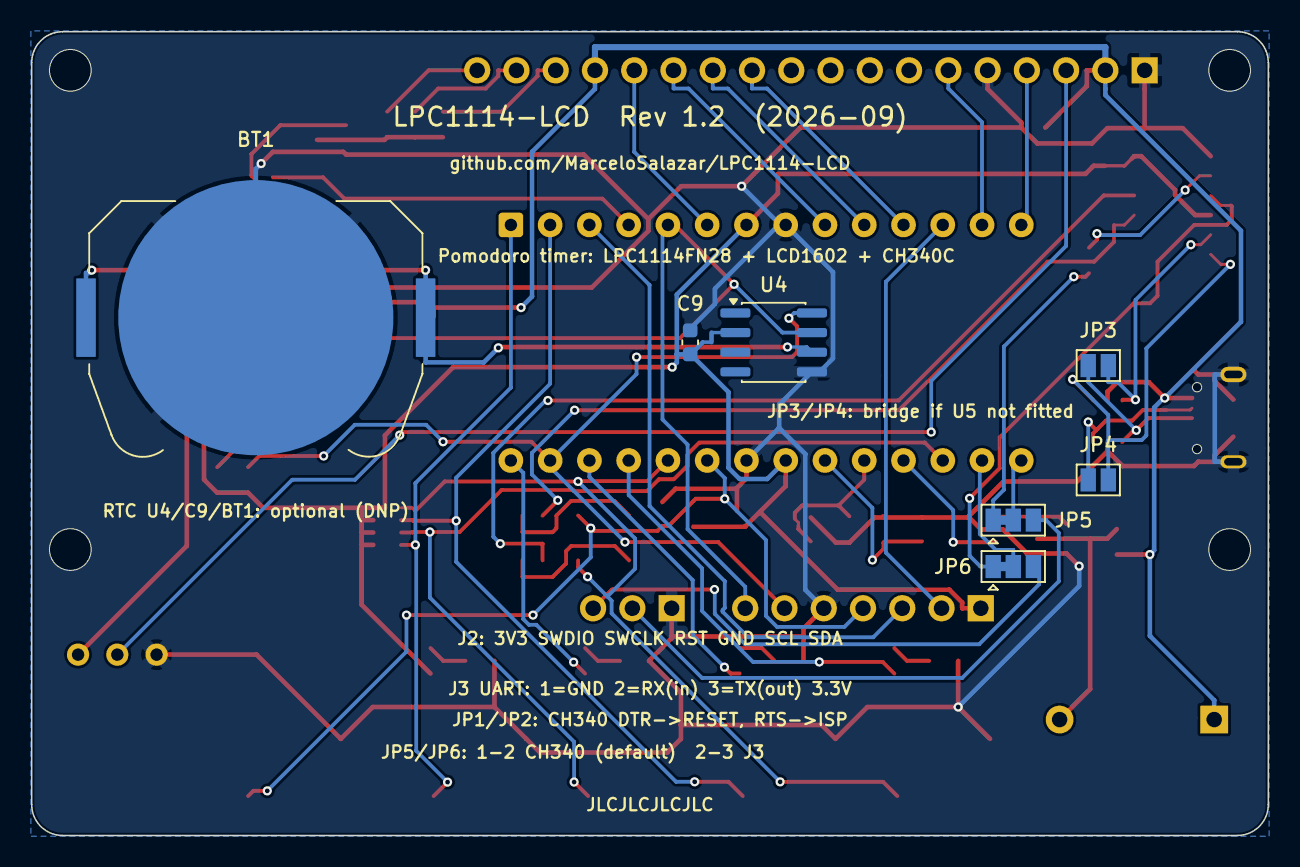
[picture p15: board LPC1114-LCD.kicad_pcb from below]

Board: 2 copper layers, 80.0 x 52.0 mm, 59 parts (7 on the bottom side), 53 nets.

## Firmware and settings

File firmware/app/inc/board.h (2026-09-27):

/*
 * board.h - LPC1114-LCD v1.2 pin map and board constants.
 *
 * Generated from the hardware design (hardware/LPC1114-LCD.kicad_sch).
 * Keep in sync with the schematic whenever the hardware changes.
 */
#ifndef BOARD_H
#define BOARD_H

/* ---------------------------------------------------------------- Clocks */
#define BOARD_XTAL_HZ           12000000UL  /* Y1, system oscillator (XTALIN/XTALOUT) */
#define BOARD_CORE_CLOCK_HZ     48000000UL  /* 12 MHz x 4 via system PLL */

/* ---------------------------------------------------------------- Pin convention
 * Each signal is described by its GPIO port (0/1) and bit number.
 * NOTE: PIO0_11, PIO1_0, PIO1_1 and PIO1_2 start in a reserved function after
 * reset: their IOCON register must select FUNC = 1 (GPIO) and digital mode (ADMODE = 1).
 */

/* ---------------------------------------------------------------- LCD 1602 (4-bit, write only: R/W tied to GND)
 * Driven push-pull at 3.3 V (HD44780/ST7066 VIH = 2.2 V). No external pull-ups.
 */
#define LCD_RS_PORT             1
#define LCD_RS_PIN              5   /* PIO1_5, DIP pin 14 */
#define LCD_E_PORT              1
#define LCD_E_PIN               4   /* PIO1_4, DIP pin 13 */
#define LCD_D4_PORT             1
#define LCD_D4_PIN              2   /* PIO1_2, DIP pin 11 (IOCON FUNC=1) */
#define LCD_D5_PORT             1
#define LCD_D5_PIN              1   /* PIO1_1, DIP pin 10 (IOCON FUNC=1) */
#define LCD_D6_PORT             1
#define LCD_D6_PIN              0   /* PIO1_0, DIP pin 9  (IOCON FUNC=1) */
#define LCD_D7_PORT             0
#define LCD_D7_PIN              6   /* PIO0_6, DIP pin 6 */

/* Backlight: NPN low-side switch, active high. PWM on CT32B0_MAT3 (IOCON FUNC=3). */
#define LCD_BL_PORT             0
#define LCD_BL_PIN              11  /* PIO0_11, DIP pin 4 (IOCON FUNC=1 for GPIO) */

/* ---------------------------------------------------------------- Buttons (active low, 10k external pull-ups) */
#define BTN_MODE_PORT           0
#define BTN_MODE_PIN            1   /* PIO0_1, DIP pin 24 - held low at reset = UART ISP */
#define BTN_UP_PORT             0
#define BTN_UP_PIN              9   /* PIO0_9, DIP pin 2 */
#define BTN_DOWN_PORT           1
#define BTN_DOWN_PIN            8   /* PIO1_8, DIP pin 17 */
#define BTN_OK_PORT             0
#define BTN_OK_PIN              8   /* PIO0_8, DIP pin 1 */

/* ---------------------------------------------------------------- LEDs (active high, 470R) */
#define LED1_PORT               0
#define LED1_PIN                2   /* PIO0_2, DIP pin 25 - red */
#define LED2_PORT               0
#define LED2_PIN                3   /* PIO0_3, DIP pin 26 - yellow */
#define LED3_PORT               0
#define LED3_PIN                7   /* PIO0_7, DIP pin 28 - green (high-current pin) */

/* ---------------------------------------------------------------- Buzzer (TDK PS1420P02CT piezo, ~2 kHz resonance)
 * NPN low side on 5 V, active high. PWM on CT16B1_MAT0 (IOCON FUNC=1).
 * 10k pull-down keeps it off during reset.
 */
#define BUZZER_PORT             1
#define BUZZER_PIN              9   /* PIO1_9, DIP pin 18 */
#define BUZZER_RESONANCE_HZ     2000UL

/* ---------------------------------------------------------------- I2C on J2 pins 6/7 (4k7 pull-ups to 3.3 V)
 * Optional RTC footprint on the bottom side (DS3231MZ, DNP by default).
 */
#define I2C_SCL_PORT            0
#define I2C_SCL_PIN             4   /* PIO0_4, DIP pin 27 */
#define I2C_SDA_PORT            0
#define I2C_SDA_PIN             5   /* PIO0_5, DIP pin 5 */
#define RTC_I2C_ADDR            0x68U   /* only if the optional DS3231MZ (U4) is fitted */

/* ---------------------------------------------------------------- UART
 * Routed to the CH340C (micro USB) by default, or to header J3 by re-bridging JP5/JP6 (2-3).
 */
#define UART_RXD_PORT           1
#define UART_RXD_PIN            6   /* PIO1_6, DIP pin 15 */
#define UART_TXD_PORT           1
#define UART_TXD_PIN            7   /* PIO1_7, DIP pin 16 */
#define UART_DEFAULT_BAUD       115200UL

#endif /* BOARD_H */

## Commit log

2026-09-26 Hardware rev 1.0: LPC1114-LCD board (KiCad 10, JLCPCB)
    - Schematic and 2-layer PCB (80x76 mm): LPC1114FN28 DIP-28, LCD1602 4-bit,
    DS3231M RTC + CR2032, CH340C USB-UART, MCP1700 3.3 V LDO, SWD 10-pin,
    LEDs, buttons, passive buzzer
    - ERC/DRC clean, schematic parity OK, fully routed
    - Fabrication outputs: JLCPCB Gerber zip, BOM, STEP model
    - Docs: design notes, schematic PDF, renders, datasheets
    - Firmware skeleton for phase 2 with board.h pin map
    - MIT license
    [LPC1114-LCD.kicad_pcb, LPC1114-LCD.kicad_sch, LPC1114-LCD.step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]
2026-09-26 Docs: link schematic PDF from README and refresh it
2026-09-26 Enclosure: 2-part 3D-printed case (FreeCAD)
    - Parametric FreeCAD script (enclosure/case.py) generating top (display)
    and base parts, joined by 4 x M3x16 screws from the bottom
    - Integrated flexure buttons, LCD window, LED/reset/contrast holes,
    buzzer grille, micro USB opening, PCB standoffs and alignment lip
    - Zero interference with the PCB assembly (LCD at real stack height)
    - STEP (parts + assembly), STL in print orientation, FCStd
    - Renders in docs/images and enclosure README
    [LPC1114-LCD_case.FCStd, case_assembly.step, case_base.step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]
2026-09-27 Hardware v1.1: JLCPCB PCBA with Basic parts, Pomodoro timer, 80x52 mm
    - Main use is now a Pomodoro timer: RTC (DS3231M) and CR2032 removed,
    timekeeping from the 12 MHz crystal; PTC fuse removed
    - SMD redesign for JLCPCB assembly: 0603/0805 passives and LEDs,
    XC6206 LDO, SS8050, B5819W, 3225 crystal, TS-1187A buttons (all Basic);
    CH340C and micro USB are the only Extended parts
    - User-soldered: LPC1114 (+socket), LCD, 10k multiturn trimmer,
    TDK PS1420P02CT piezo buzzer, USBLC6-2SC6, J2 (1x7 SWD+I2C) and
    J3 (1x3 UART) pads
    - PCB reduced from 80x76 to 80x52 mm; ERC/DRC clean, parity OK, fully routed
    - JLCPCB BOM + CPL and hand-solder list generated by export_fab.ps1
    - Enclosure update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
    [LPC1114-LCD.kicad_pcb, LPC1114-LCD.kicad_sch, LPC1114-LCD.step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]
2026-09-27 Hardware v1.2: optional RTC (DNP), USBLC6 bypass and UART source selection
    - Optional RTC on the bottom side, marked DNP: DS3231MZ+ (U4) between the
    DIP rows, C9 and a Keystone 3034 SMD CR2032 holder (BT1) on the J2 I2C bus;
    excluded from the JLCPCB BOM/CPL, listed in LPC1114-LCD_DNP_options.csv
    - USB D+/D- now flow through U5 (USBLC6-2SC6); JP3/JP4 (bottom, open)
    bypass it when U5 is not fitted
    - UART source selection: JP5/JP6 3-pad jumpers (bottom), 1-2 CH340
    (bridged by default), 2-3 external UART on J3, so both never connect together
    - ERC/DRC clean, schematic parity OK (DNP attributes), fully connected
    - Enclosure: 1 mm base pocket for the optional battery holder
    - Docs: jumper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
    [LPC1114-LCD.kicad_pcb, LPC1114-LCD.kicad_sch, LPC1114-LCD.step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]
